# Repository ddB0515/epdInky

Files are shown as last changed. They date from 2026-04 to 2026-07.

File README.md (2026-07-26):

# epdInky

ESP32-P4 board for driving RAW E-Ink display panels, epdInky is powered by ESP32-P4 and companion ESP32-C6 for WiFi

If you wanna get one for yourself hop to shop: https://shop.fasani.de/en_US/products/epdinky

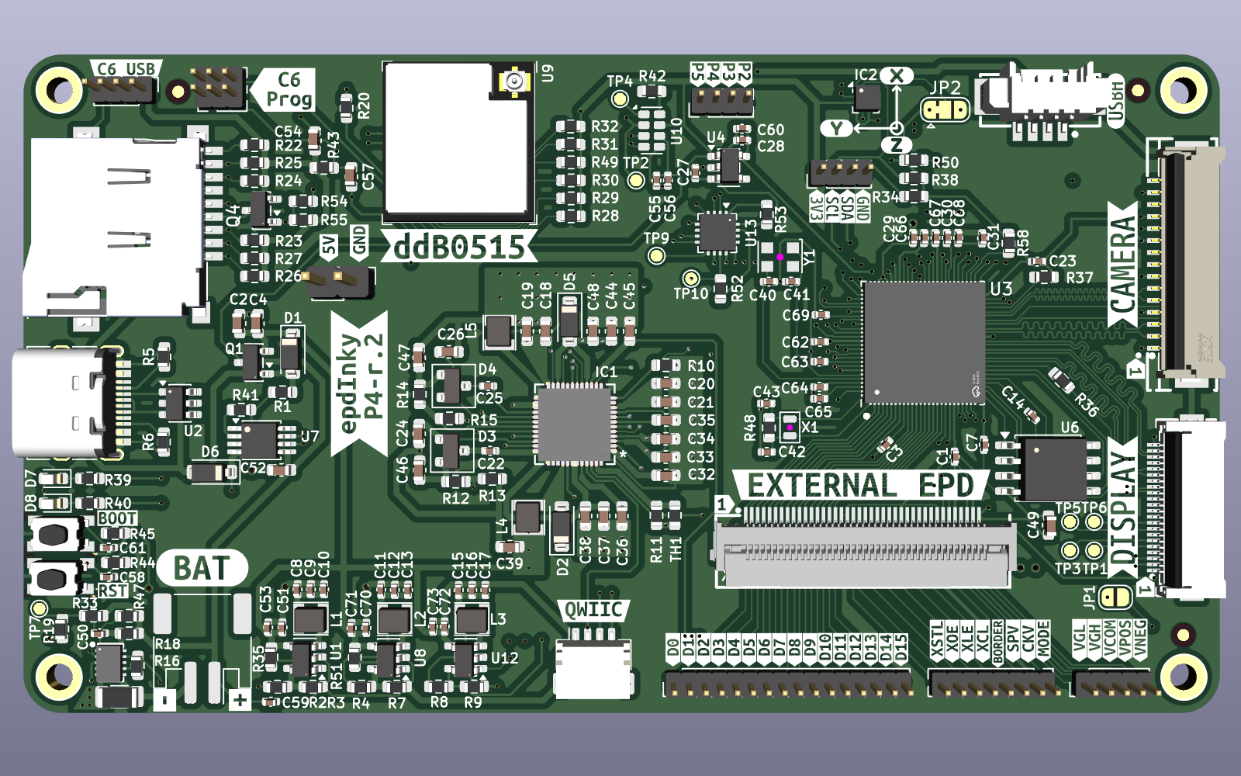
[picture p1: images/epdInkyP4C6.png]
Front Photo


# Hardware Specifications

## SoC
- **Model:** Espressif Systems ESP32-P4NRW32

## CPU
- Dual-core 32-bit RISC-V High-Performance (HP) CPU
  - Up to **400 MHz**
  - AI instruction extension
  - Single-precision FPU
- Single-core RISC-V Low-Power (LP) MCU
  - Up to **40 MHz**

## Memory
- 768 KB HP L2MEM (shared by dual-core CPU)
- 32 KB LP SRAM
- 8 KB TCM (for LP MCU core)
- 32 MB PSRAM

## Storage
- **Internal ROM**
  - 128 KB HP ROM
  - 16 KB LP ROM
- **Flash**
  - 32 MB QSPI NOR Flash
- **Expandable**
  - MicroSD card slot

## Graphics & Video
- **GPU:** 2D Pixel Processing Accelerator (PPA)
- **VPU:** H.264 and JPEG codec support

## Camera
- MIPI CSI camera sensor interface

## Wireless
- **Companion chip:** ESP32-C6
- 2.4 GHz Wi-Fi 6
- Bluetooth 5.x Low Energy (LE)
- IEEE 802.15.4 radio
  - Zigbee
  - Thread
  - Matter

## USB
- USB Type-C port
  - Power
  - Debugging

## Sensors
- 6-axis KXTJ3-1057 motion sensor
  - Portrait/landscape orientation detection

## Miscellaneous
- Reset button
- Boot button
- Power LED
- Battery LED
- RV-3028-C7 RTC with timed interrupt wake-up support

## Power Supply
- 5V via USB Type-C
- JST battery connector

## Dimensions
- **100 × 55 mm**

## I2C peripherals:

- TPS651851RSLR - PMIC for e-Ink (I2C addr: 0x68)
- KXTJ3-1057 - 3-axis accelerometar  (I2C addr: 0x0F)
- RV-3028-C7 - RTC (I2C addr: 0x52)
- STC3115AIQT - Fuel guage (I2C addr: 0x70)
- TCA6408ARGTR - GPIO Extender (I2C addr: 0x21)
- TP4056 Battery charger (500mA)

Software side:

Currently examples use [FastEPD](https://github.com/bitbank2/FastEPD/) library and plan is to support
* epdiy
* TRMNL
* HA (custom FW)

List of panels tested and working (keep in mind 2/4bit support for panels is still WIP and will be some time to do it)

| Panel | Resulution | 8/16bit | Gray levels | Pin count | Tested |
| ----- | --- | --- | --- | --- | --- |
| ED070KH1 | 1680x1264 | 16 bit | 1/2/4 | 40 pin | 1 bit only |
| ED097TC2 | 1200x825 | 8 bit | 1/2/4 | 33 pin | 1 bit only |
| ES133TT3 | 2200x1650 | 16 bit | 1/2/4 | 39 pin | 1 bit only |
| ED115OC1 | 2760x2070 | 16 bit | 1/2/4 | 40 pin | 1 bit only |
| ED113TC1| 2400x1034 | 16 bit | 1/2/4 | 50 pin | 1 bit only |
| ED052TC4 | 1280x720 | 8 bit | 1/2/4 | 50 pin | 1 bit only |
| ED060SCN | 800x600 | 8 bit| 1/2/4 | 34 pin | 1 bit only |
| ED060SCP | 800x600 | 8 bit| 1/2/4 | 34 pin | 1 bit only |
| ED060SC7 | 800x600 | 8 bit| 1/2/4 | 34 pin | 1 bit only |
| ET017QG1 |320x240| 8 bit | 1/2/4 | 39 pin| 1 bit only |
| ED103TC2 | 1872x1404 | 16 bit | 1/2/4 | 40 pin| 1 bit only |
| ED078KC1 | 1872x1404 | 16 bit | 1/2/4 | 40 pin| 1 bit only |
| | | | | | |
| | | | | | |

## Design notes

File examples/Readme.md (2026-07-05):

# Examples

This directory contains example applications demonstrating the capabilities of **epdInky** and the supported hardware peripherals. The examples range from basic e-paper rendering to Wi-Fi, camera, MIPI DSI, and JSON-based applications.

## Directory Structure

```text
examples/
├── epd/
│   ├── basic/             # Basic e-paper drawing example
│   ├── calendar/          # Calendar application
│   ├── FastJsonBasic/     # FastJson basic usage
│   ├── FastJsonBLE/       # FastJson over Bluetooth LE
│   └── matrix_editor/     # Interactive pixel matrix editor
├── csi/                   # MIPI CSI camera examples
├── mipi/
│   └── mipi_dsi_a260/     # MIPI DSI display example
└── wifi/                  # Wi-Fi networking examples
```

## Requirements

Before building any example, make sure you have:

- ESP-IDF installed and configured
- A supported ESP32 target
- The required display and peripherals connected
- All project dependencies installed

## Building an Example

Each example is an independent ESP-IDF project.

```bash
cd examples/epd/basic

idf.py set-target esp32p4
idf.py build
idf.py flash monitor
```

Replace the directory with the example you want to build.

## Examples

### EPD

| Example | Description |
|---|---|
| **basic** | A minimal example demonstrating how to initialize the e-paper display and render basic graphics and text. |
| **calendar** | Displays a calendar interface using the e-paper display, including text rendering and layout management. |
| **matrix_editor** | Interactive pixel editor demonstrating framebuffer manipulation, drawing primitives, and partial display updates. |
| **FastJsonBasic** | Demonstrates using the FastJson library for parsing and generating JSON data. |
| **FastJsonBLE** | Demonstrates Bluetooth LE communication using FastJson for data serialization and exchange. |

### CSI

Camera interface examples demonstrating:

- MIPI CSI initialization
- Frame capture
- Image processing pipelines

### MIPI

#### `mipi_dsi_a260`

Demonstrates driving a MIPI DSI display, including:

- Display initialization
- Framebuffer rendering
- Screen updates

### Wi-Fi

Networking examples showing how to:

- Connect to a Wi-Fi access point
- Perform network communication
- Build connected applications

## Adding New Examples

New examples should follow the standard ESP-IDF project layout:

```text
example_name/
├── main/
├── CMakeLists.txt
├── README.md
└── sdkconfig.defaults
```

Keeping each example self-contained makes it easier to build, understand, and maintain.

## Hardware Requirements

Some examples require additional hardware, such as:

- E-paper display
- MIPI DSI display
- MIPI CSI camera
- Bluetooth LE device
- Wi-Fi network

Refer to each example's source code and configuration for hardware-specific requirements.

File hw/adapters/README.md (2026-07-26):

# List of adapters so far that are manufactured and tested

### AllInOneAdapter


This adapter have:<br>
* 40 pin (this is double side contacts) so some panels will need to reverse it (due to opposite pins but works)<br>
* 34 pin (this is double side contacts) so some panels will need to reverse it (due to opposite pins but works)<br>
* 33 pin (bottom side contacts) as didn't find any reverse panels but if do in future can be updated to support it <br>

### AllInOneAdapter-39pin

This adapter have 3 39pin connectors for different models but different style panels could be connected (check schematic)<br>
* ED133UT2<br>
* ED060SC4<br>
* ET107QG1 (U2 on PCB is not populated (for backlight)<br>

### ED052TC4-Adapter


### ED060SC7-Adapter


### ED113TC1-Adapter


### EPD-Adapter
This is generic universal adapter for prototyping when want to have exposed pads (with header ot not) 



### ES133TT3-Adapter


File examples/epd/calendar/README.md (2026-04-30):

| Supported Targets | ESP32-P4 |
| --- | --- |

# EPD Basic DEMOs

This example shows how to use FASTEPD library with epdInky ESP32-P4C6.r2 board

# Cloning repo

YOu have few ways doing checkout code and compile

```
git clone --recurse-submodules https://github.com/ddB0515/epdInky.git

or if you have cloned it already (you need to update submodule)

git submodule update --init --recursive

```
After this step is done you need manually to create one file in component (this is workaround until FastEPD gets IDF component registy)

Put this content into: components/FastEPD/idf_component.yml
```
version: "2.0.1"
description: "Optimized library for driving parallel eink displays with the ESP32"
url: "https://github.com/bitbank2/FastEPD"
license: "Apache-2.0 license"
```
Without this you will get errors building 
```
CMake Error at /home/user/.espressif/v6.0/esp-idf/tools/cmake/build.cmake:695 (message):
  ERROR: The "path" field in the manifest file
  "/home/user/epdInky/examples/epd/matrix_editor/main/components/FastEPD/idf_component.yml"
  does not point to a directory.  You can safely remove this field from the
  manifest if this project is an example copied from a component repository.
  The dependency will be downloaded from the ESP component registry.
```

## How to use the example

### Hardware Required

* An epdInky ESP32-P4C6.r2 development board, adapter for eInk panel (check main README.md)
* SDCard needs to be present (as is part of demo) but used for test purposes

### Hardware Connection

The connection between epdInky ESP32-P4C6.r2 is provided via 40pin FPC cable to adapter which enable connection to eInk panel

### Configure

To change panel details refer to `main.c` and change details for your panel

```
If you are using 8bit panel you have to change board config (BB_PANEL_EPDINKY_P4 or BB_PANEL_EPDINKY_P4_16)

8Bit
    int rc = bbepInitPanel(&bbep, BB_PANEL_EPDINKY_P4, 20000000);

16Bit
    int rc = bbepInitPanel(&bbep, BB_PANEL_EPDINKY_P4_16, 20000000);

```
Next section is PANEL itself (size W/H and flags) this example I'm using ED113TC1 panel
```
bbepSetPanelSize(&bbep, 2400, 1034, BB_PANEL_FLAG_MIRROR_Y, -1000); // ED113TC1
```

after all is done you can BUILD

Run `idf.py menuconfig` and go to `Example Configuration`:
2 Options needs to be enabled
- PSRAM
- Chip ID to be < 3.0 (old version)
(this should be already enabled in default sdkconfig)

### Build and Flash

Run `idf.py -p PORT build flash monitor` to build, flash and monitor the project. A LVGL widget should show up on the LCD as expected.

The first time you run `idf.py` for the example will cost extra time as the build system needs to address the component dependencies and downloads the missing components from the ESP Component Registry into `managed_components` folder.

(To exit the serial monitor, type ``Ctrl-]``.)

See the [Getting Started Guide](https://docs.espressif.com/projects/esp-idf/en/latest/get-started/index.html) for full steps to configure and use ESP-IDF to build projects.

# USAGE

In my case when connected to WiFI find your IP address and connect to it (in my case was: 192.168.1.82)
So you need to open
```
http://192.168.1.82/matrix
```
And you should be on Matrix Editor and ready to modify your example as you wish, once you have your matrix for the panel you could open PR for FastEPD or here

### Example Output

```bash
...
Build:Jul 10 2024
rst:0x17 (CHIP_USB_UART_RESET),boot:0xc (SPI_FAST_FLASH_BOOT)
Core0 Saved PC:0x40009034
--- 0x40009034: s_test_psram at /home/dale/.espressif/v6.0/esp-idf/components/esp_psram/system_layer/esp_psram.c:617
Core1 Saved PC:0x4fc012c6
--- 0x4fc012c6: ets_ds_enable in ROM
SPI mode:DIO, clock div:1
load:0x4ff33ce0,len:0x15e0
load:0x4ff29ed0,len:0xe18
load:0x4ff2cbd0,len:0x359c
entry 0x4ff29eda
I (27) boot: ESP-IDF v6.0 2nd stage bootloader
I (28) boot: compile time Apr 30 2026 13:01:58
I (28) boot: Multicore bootloader
I (30) boot: chip revision: v1.0
I (30) boot: efuse block revision: v0.3
I (34) boot.esp32p4: SPI Speed      : 80MHz
I (38) boot.esp32p4: SPI Mode       : DIO
I (42) boot.esp32p4: SPI Flash Size : 2MB
I (45) boot: Enabling RNG early entropy source...
I (50) boot: Partition Table:
I (53) boot: ## Label            Usage          Type ST Offset   Length
I (59) boot:  0 nvs              WiFi data        01 02 00009000 00006000
I (65) boot:  1 phy_init         RF data          01 01 0000f000 00001000
I (72) boot:  2 factory          factory app      00 00 00010000 00100000
I (79) boot: End of partition table
I (82) esp_image: segment 0: paddr=00010020 vaddr=40030020 size=17998h ( 96664) map
I (104) esp_image: segment 1: paddr=000279c0 vaddr=30100000 size=00068h (   104) load
I (106) esp_image: segment 2: paddr=00027a30 vaddr=4ff00000 size=085e8h ( 34280) load
I (114) esp_image: segment 3: paddr=00030020 vaddr=40000020 size=24e7ch (151164) map
I (138) esp_image: segment 4: paddr=00054ea4 vaddr=4ff085e8 size=076c0h ( 30400) load
I (145) esp_image: segment 5: paddr=0005c56c vaddr=4ff0fd00 size=03258h ( 12888) load
I (152) boot: Loaded app from partition at offset 0x10000
I (153) boot: Disabling RNG early entropy source...
I (165) hex_psram: vendor id    : 0x0d (AP)
I (165) hex_psram: Latency      : 0x01 (Fixed)
I (166) hex_psram: DriveStr.    : 0x00 (25 Ohm)
I (166) hex_psram: dev id       : 0x03 (generation 4)
I (171) hex_psram: density      : 0x07 (256 Mbit)
I (175) hex_psram: good-die     : 0x06 (Pass)
I (179) hex_psram: SRF          : 0x02 (Slow Refresh)
I (184) hex_psram: BurstType    : 0x00 ( Wrap)
I (188) hex_psram: BurstLen     : 0x03 (2048 Byte)
I (193) hex_psram: BitMode      : 0x01 (X16 Mode)
I (197) hex_psram: Readlatency  : 0x04 (14 cycles@Fixed)
I (202) hex_psram: DriveStrength: 0x00 (1/1)
I (206) MSPI Timing: Enter psram timing tuning
I (383) esp_psram: Found 32MB PSRAM device
I (384) esp_psram: Speed: 200MHz
I (387) hex_psram: psram CS IO is dedicated
I (387) cpu_start: Multicore app
I (1372) esp_psram: SPI SRAM memory test OK
I (1383) cpu_start: GPIO 38 and 37 are used as console UART I/O pins
I (1383) cpu_start: Pro cpu start user code
I (1383) cpu_start: cpu freq: 360000000 Hz
I (1385) app_init: Application information:
I (1389) app_init: Project name:     basic
I (1393) app_init: App version:      1eac6ff-dirty
I (1397) app_init: Compile time:     Apr 30 2026 13:01:56
I (1402) app_init: ELF file SHA256:  042d7002f...
I (1407) app_init: ESP-IDF:          v6.0
I (1411) efuse_init: Min chip rev:     v1.0
I (1415) efuse_init: Max chip rev:     v1.99 
I (1419) efuse_init: Chip rev:         v1.0
I (1423) heap_init: Initializing. RAM available for dynamic allocation:
I (1429) heap_init: At 4FF15970 len 00025650 (149 KiB): RETENT_RAM
I (1435) heap_init: At 4FF3AFC0 len 00004BF0 (18 KiB): RAM
I (1440) heap_init: At 4FF40000 len 00060000 (384 KiB): RAM
I (1446) heap_init: At 50108080 len 00007F80 (31 KiB): RTCRAM
I (1451) heap_init: At 30100068 len 00001F98 (7 KiB): TCM
I (1456) esp_psram: Adding pool of 32768K of PSRAM memory to heap allocator
I (1463) spi_flash: detected chip: generic
I (1466) spi_flash: flash io: dio
W (1469) spi_flash: Detected size(16384k) larger than the size in the binary image header(2048k). Using the size in the binary image header.
I (1482) sleep_gpio: Configure to isolate all GPIO pins in sleep state
I (1488) sleep_gpio: Enable automatic switching of GPIO sleep configuration
I (1495) main_task: Started on CPU0
I (1505) esp_psram: Reserving pool of 32K of internal memory for DMA/internal allocations
I (1505) main_task: Calling app_main()
I (1505) eInky-P4: i2c_master_init ESP_OK
I (1515) eInky-P4: tca6408_init...
     0  1  2  3  4  5  6  7  8  9  a  b  c  d  e  f
00: -- -- -- -- -- -- -- -- -- -- -- -- -- -- -- 0f 
10: -- -- -- -- -- -- -- -- -- -- -- -- -- -- -- -- 
20: -- 21 -- -- -- -- -- -- -- -- -- -- -- -- -- -- 
30: -- -- -- -- -- -- -- -- -- -- -- -- -- -- -- -- 
40: -- -- -- -- -- -- -- -- -- -- -- -- -- -- -- -- 
50: -- -- 52 -- -- -- -- -- -- -- -- -- -- -- -- -- 
60: -- -- -- -- -- -- -- -- 68 -- -- -- -- -- -- -- 
70: 70 -- -- -- -- -- -- -- -- -- -- -- -- -- -- -- 
W (1595) i2c.master: Timeout value exceeds the maximum supported value, rounded down to maximum supported value: 53687091 us
...
W (46865) i2c.master: Timeout value exceeds the maximum supported value, rounded down to maximum supported value: 53687091 us
I (48315) main_task: Returned from app_main()
...
```

## Troubleshooting

For any technical queries, please open an [issue](https://github.com/ddB0515/epdInky/issues) on GitHub. We will get back to you soon.

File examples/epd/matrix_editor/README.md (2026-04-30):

| Supported Targets | ESP32-P4 |
| --- | --- |

# EPD Matrix Editor

This example shows how to use Web GUI for custom Matrix editor needed to make for new panels to get 16 levels (4bit) gray colours.
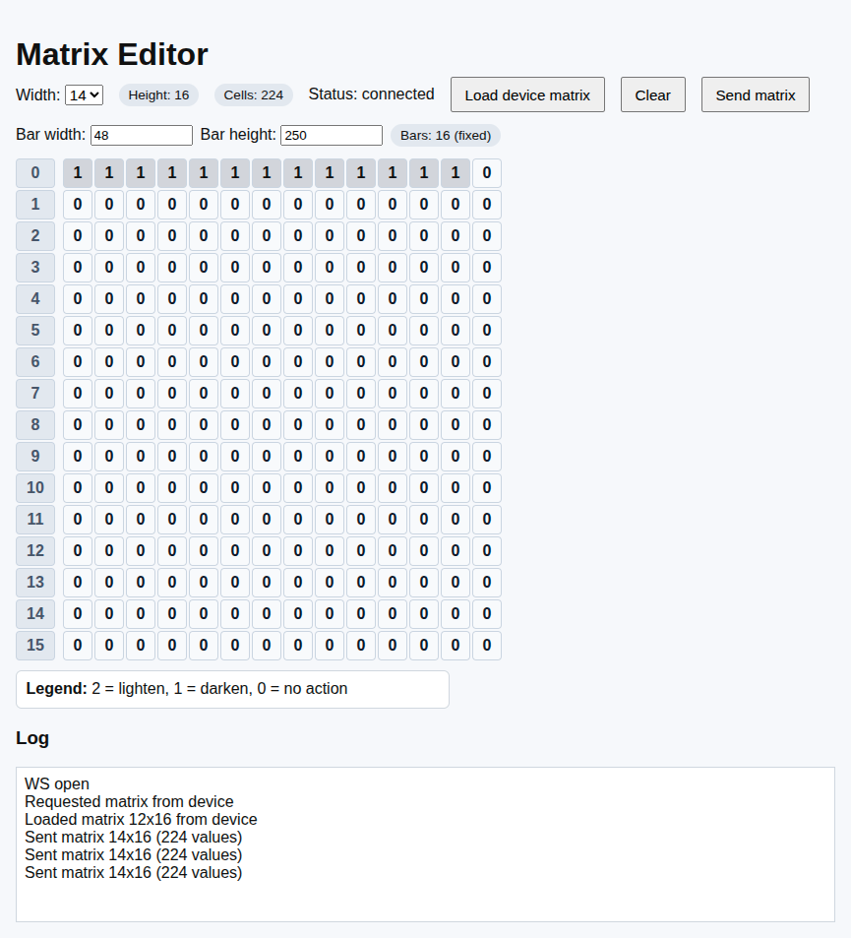
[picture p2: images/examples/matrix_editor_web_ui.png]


When run matrix editor on a device you going to be able to change settings in realtime (check image top) and adjust it on the fly

DEFAULT

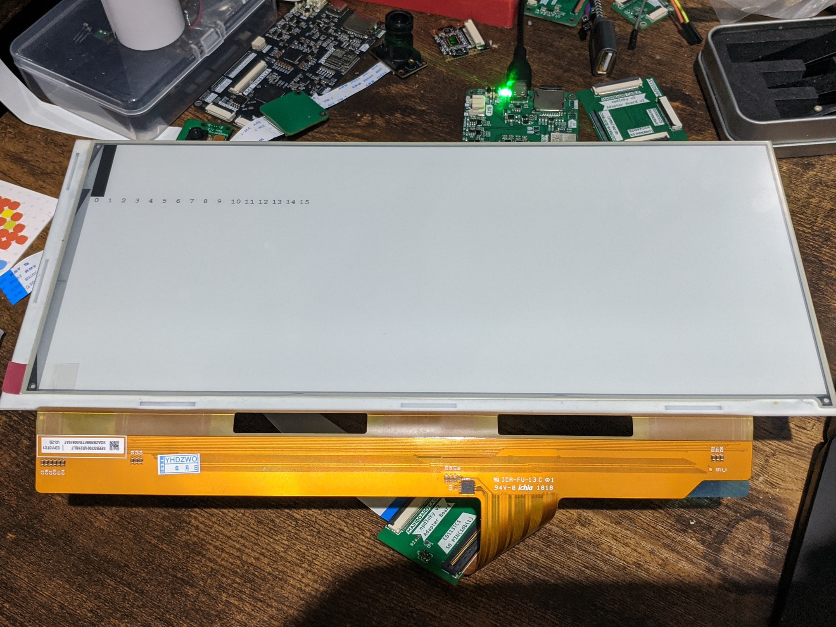
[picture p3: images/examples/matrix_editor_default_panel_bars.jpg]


MODIFIED

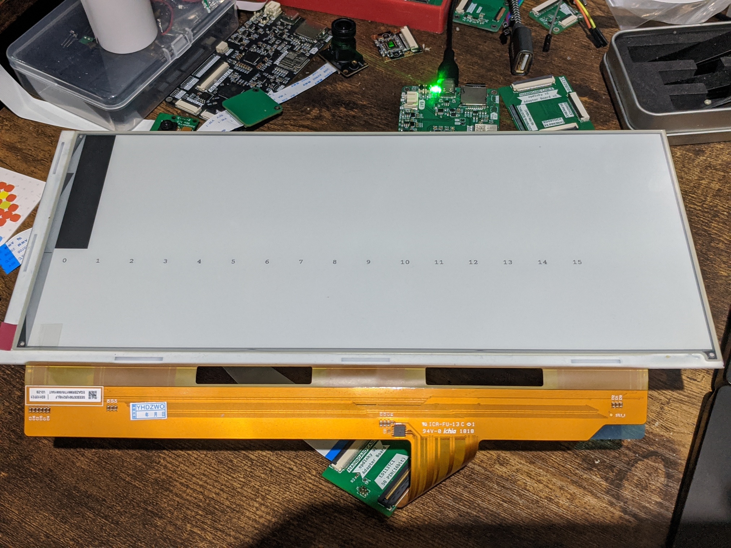
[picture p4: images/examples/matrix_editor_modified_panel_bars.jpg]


# Cloning repo

YOu have few ways doing checkout code and compile

```
git clone --recurse-submodules https://github.com/ddB0515/epdInky.git

or if you have cloned it already (you need to update submodule)

git submodule update --init --recursive

```
After this step is done you need manually to create one file in component (this is workaround until FastEPD gets IDF component registy)

Put this content into: components/FastEPD/idf_component.yml
```
version: "2.0.1"
description: "Optimized library for driving parallel eink displays with the ESP32"
url: "https://github.com/bitbank2/FastEPD"
license: "Apache-2.0 license"
```
Without this you will get errors building 
```
CMake Error at /home/user/.espressif/v6.0/esp-idf/tools/cmake/build.cmake:695 (message):
  ERROR: The "path" field in the manifest file
  "/home/user/epdInky/examples/epd/matrix_editor/main/components/FastEPD/idf_component.yml"
  does not point to a directory.  You can safely remove this field from the
  manifest if this project is an example copied from a component repository.
  The dependency will be downloaded from the ESP component registry.
```

## How to use the example

### Hardware Required

* An epdInky ESP32-P4C6.r2 development board, adapter for eInk panel (check main README.md)
* SDCard needs to be present (as is part of demo) but used for test purposes
### Hardware Connection

The connection between epdInky ESP32-P4C6.r2 is provided via 40pin FPC cable to adapter which enable connection to eInk panel

### Configure

In `main.h` before you build change default WIFI settings to your network so you can connect to WiFi and use editor

```
#define EXAMPLE_ESP_WIFI_SSID      "WIFI_SSID"
#define EXAMPLE_ESP_WIFI_PASS      "WIFI_PASSWORD"
```
To change panel details refer to `epd_functions.c` and change details for your panel

```
If you are using 8bit panel you have to change board config (BB_PANEL_EPDINKY_P4 or BB_PANEL_EPDINKY_P4_16)

8Bit
    int rc = bbepInitPanel(&bbep, BB_PANEL_EPDINKY_P4, 20000000); //BB_PANEL_EPDINKY_P4_16

16Bit
    int rc = bbepInitPanel(&bbep, BB_PANEL_EPDINKY_P4_16, 20000000); //BB_PANEL_EPDINKY_P4_16

```
Next section is PANEL itself (size W/H and flags) this example I'm using ED113TC1 panel
```
bbepSetPanelSize(&bbep, 2400, 1034, BB_PANEL_FLAG_MIRROR_Y, 0); // ED113TC1
```

after all is done you can BUILD

Run `idf.py menuconfig` and go to `Example Configuration`:
2 Options needs to be enabled
- PSRAM
- Chip ID to be < 3.0 (old version)
(this should be already enabled in default sdkconfig)

### Build and Flash

Run `idf.py -p PORT build flash monitor` to build, flash and monitor the project. A LVGL widget should show up on the LCD as expected.

The first time you run `idf.py` for the example will cost extra time as the build system needs to address the component dependencies and downloads the missing components from the ESP Component Registry into `managed_components` folder.

(To exit the serial monitor, type ``Ctrl-]``.)

See the [Getting Started Guide](https://docs.espressif.com/projects/esp-idf/en/latest/get-started/index.html) for full steps to configure and use ESP-IDF to build projects.

# USAGE

In my case when connected to WiFI find your IP address and connect to it (in my case was: 192.168.1.82)
So you need to open
```
http://192.168.1.82/matrix
```
And you should be on Matrix Editor and ready to modify your example as you wish, once you have your matrix for the panel you could open PR for FastEPD or here

### Example Output

```bash
...
Build:Jul 10 2024
rst:0x17 (CHIP_USB_UART_RESET),boot:0x31c (SPI_FAST_FLASH_BOOT)
Core0 Saved PC:0x40009024
--- 0x40009024: s_test_psram at /home/user/.espressif/v6.0/esp-idf/components/esp_psram/system_layer/esp_psram.c:617
Core1 Saved PC:0x4fc012ca
--- 0x4fc012ca: ets_ds_enable in ROM
SPI mode:DIO, clock div:1
load:0x4ff33ce0,len:0x15e0
load:0x4ff29ed0,len:0xe18
load:0x4ff2cbd0,len:0x359c
entry 0x4ff29eda
I (28) boot: ESP-IDF v6.0 2nd stage bootloader
I (28) boot: compile time Apr 29 2026 22:49:13
I (28) boot: Multicore bootloader
I (30) boot: chip revision: v1.0
I (31) boot: efuse block revision: v0.3
I (34) boot.esp32p4: SPI Speed      : 80MHz
I (38) boot.esp32p4: SPI Mode       : DIO
I (42) boot.esp32p4: SPI Flash Size : 2MB
I (46) boot: Enabling RNG early entropy source...
I (50) boot: Partition Table:
I (53) boot: ## Label            Usage          Type ST Offset   Length
I (59) boot:  0 nvs              WiFi data        01 02 00009000 00006000
I (66) boot:  1 phy_init         RF data          01 01 0000f000 00001000
I (72) boot:  2 factory          factory app      00 00 00010000 00100000
I (79) boot: End of partition table
I (82) esp_image: segment 0: paddr=00010020 vaddr=40080020 size=3df24h (253732) map
I (127) esp_image: segment 1: paddr=0004df4c vaddr=30100000 size=00068h (   104) load
I (129) esp_image: segment 2: paddr=0004dfbc vaddr=4ff00000 size=0205ch (  8284) load
I (133) esp_image: segment 3: paddr=00050020 vaddr=40000020 size=7aa58h (502360) map
I (212) esp_image: segment 4: paddr=000caa80 vaddr=4ff0205c size=0e7cch ( 59340) load
I (223) esp_image: segment 5: paddr=000d9254 vaddr=4ff10880 size=035f8h ( 13816) load
I (231) boot: Loaded app from partition at offset 0x10000
I (231) boot: Disabling RNG early entropy source...
I (243) hex_psram: vendor id    : 0x0d (AP)
I (243) hex_psram: Latency      : 0x01 (Fixed)
I (243) hex_psram: DriveStr.    : 0x00 (25 Ohm)
I (244) hex_psram: dev id       : 0x03 (generation 4)
I (248) hex_psram: density      : 0x07 (256 Mbit)
I (253) hex_psram: good-die     : 0x06 (Pass)
I (257) hex_psram: SRF          : 0x02 (Slow Refresh)
I (262) hex_psram: BurstType    : 0x00 ( Wrap)
I (266) hex_psram: BurstLen     : 0x03 (2048 Byte)
I (270) hex_psram: BitMode      : 0x01 (X16 Mode)
I (275) hex_psram: Readlatency  : 0x04 (14 cycles@Fixed)
I (280) hex_psram: DriveStrength: 0x00 (1/1)
I (284) MSPI Timing: Enter psram timing tuning
I (461) esp_psram: Found 32MB PSRAM device
I (462) esp_psram: Speed: 200MHz
I (465) hex_psram: psram CS IO is dedicated
I (465) cpu_start: Multicore app
I (1450) esp_psram: SPI SRAM memory test OK
I (1461) cpu_start: GPIO 38 and 37 are used as console UART I/O pins
I (1461) cpu_start: Pro cpu start user code
I (1461) cpu_start: cpu freq: 360000000 Hz
I (1463) app_init: Application information:
I (1467) app_init: Project name:     matrix_editor
I (1472) app_init: App version:      e2e2744
I (1476) app_init: Compile time:     Apr 29 2026 22:49:11
I (1481) app_init: ELF file SHA256:  e76bba324...
I (1485) app_init: ESP-IDF:          v6.0
I (1489) efuse_init: Min chip rev:     v1.0
I (1493) efuse_init: Max chip rev:     v1.99 
I (1497) efuse_init: Chip rev:         v1.0
I (1501) heap_init: Initializing. RAM available for dynamic allocation:
I (1507) heap_init: At 4FF17810 len 000237B0 (141 KiB): RETENT_RAM
I (1513) heap_init: At 4FF3AFC0 len 00004BF0 (18 KiB): RAM
I (1518) heap_init: At 4FF40000 len 00060000 (384 KiB): RAM
I (1524) heap_init: At 50108080 len 00007F80 (31 KiB): RTCRAM
I (1529) heap_init: At 30100068 len 00001F98 (7 KiB): TCM
I (1534) esp_psram: Adding pool of 32768K of PSRAM memory to heap allocator
I (1542) spi_flash: detected chip: generic
I (1545) spi_flash: flash io: dio
W (1548) spi_flash: Detected size(16384k) larger than the size in the binary image header(2048k). Using the size in the binary image header.
I (1579) sleep_gpio: Configure to isolate all GPIO pins in sleep state
I (1584) sleep_gpio: Enable automatic switching of GPIO sleep configuration
I (1591) H_SDIO_DRV: sdio_data_to_rx_buf_task started
I (1591) main_task: Started on CPU0
I (1601) esp_psram: Reserving pool of 32K of internal memory for DMA/internal allocations
I (1611) main_task: Calling app_main()
I (1611) eInky-P4: i2c_master_init ESP_OK
I (1611) eInky-P4: tca6408_init...
     0  1  2  3  4  5  6  7  8  9  a  b  c  d  e  f
00: -- -- -- -- -- -- -- -- -- -- -- -- -- -- -- 0f 
10: -- -- -- -- -- -- -- -- -- -- -- -- -- -- -- -- 
20: -- 21 -- -- -- -- -- -- -- -- -- -- -- -- -- -- 
30: -- -- -- -- -- -- -- -- -- -- -- -- -- -- -- -- 
40: -- -- -- -- -- -- -- -- -- -- -- -- -- -- -- -- 
50: -- -- 52 -- -- -- -- -- -- -- -- -- -- -- -- -- 
60: -- -- -- -- -- -- -- -- 68 -- -- -- -- -- -- -- 
70: 70 -- -- -- -- -- -- -- -- -- -- -- -- -- -- -- 
I (1661) epd_functions: FastEPD init
I (1661) epd_functions: bbepInitPanel returned 0
W (1671) epd_functions: EPD not initialized; call epd_init() first
W (1671) epd_functions: bbepSetCustomMatrix OK
W (1741) i2c.master: Timeout value exceeds the maximum supported value, rounded down to maximum supported value: 53687091 us
W (1741) i2c.master: Timeout value exceeds the maximum supported value, rounded down to maximum supported value: 53687091 us
W (3731) epd_functions: bbepFullUpdate OK
I (3731) sd_card_fns: Initializing SD card
I (3731) sd_card_fns: Using SDMMC peripheral
I (3731) sd_card_fns: Mounting filesystem
I (3771) sd_card_fns: Filesystem mounted
Name: SD32G
Type: SDHC
Speed: 20.00 MHz (limit: 20.00 MHz)
Size: 29819MB
CSD: ver=2, sector_size=512, capacity=61069312 read_bl_len=9
SSR: bus_width=4
I (3781) sd_card_fns: Opening file /sdcard/hello.txt
I (3821) sd_card_fns: File written
I (3821) transport: Attempt connection with slave: retry[0]
W (3821) H_SDIO_DRV: Reset slave using GPIO[54]
I (3821) os_wrapper_esp: GPIO [54] configured
I (5351) sdio_wrapper: SDIO master: Slot 1, Data-Lines: 4-bit Freq(KHz)[40000 KHz]
I (5351) sdio_wrapper: GPIOs: CLK[18] CMD[19] D0[23] D1[22] D2[21] D3[20] Slave_Reset[54]
I (5351) sdio_wrapper: Queues: Tx[20] Rx[20] SDIO-Rx-Mode[1]
I (5391) sdio_wrapper: Function 0 Blocksize: 512
I (5391) sdio_wrapper: Function 1 Blocksize: 512
I (5491) H_SDIO_DRV: Card init success, TRANSPORT_RX_ACTIVE
I (5491) transport: set_transport_state: 1
I (5491) transport: Waiting for esp_hosted slave to be ready
I (5591) H_SDIO_DRV: SDIO Host operating in STREAMING MODE
I (5591) H_SDIO_DRV: Open data path at slave
I (5591) H_SDIO_DRV: Starting SDIO process rx task
I (5611) H_SDIO_DRV: Received ESP_PRIV_IF type message
I (5611) transport: Received INIT event from ESP32 peripheral
I (5611) transport: EVENT: 12
I (5621) transport: Identified slave [esp32c6]
I (5621) transport: SDIO mode: slave: streaming, host: streaming
I (5631) transport: EVENT: 11
I (5631) transport: capabilities: 0xd
I (5631) transport: Features supported are:
I (5641) transport:      * WLAN
I (5641) transport:        - HCI over SDIO
I (5641) transport:        - BLE only
I (5641) transport: EVENT: 13
I (5651) transport: ESP board type is : 13 

I (5651) transport: Base transport is set-up, TRANSPORT_TX_ACTIVE
I (5661) H_API: Transport active
I (5661) transport: Slave chip Id[12]
I (5661) transport: raw_tp_dir[-], flow_ctrl: low[60] high[80]
I (5671) transport: transport_delayed_init
I (5671) esp_cli: Registering command: crash
I (5681) esp_cli: Registering command: reboot
I (5681) esp_cli: Registering command: mem-dump
I (5691) esp_cli: Registering command: task-dump
I (5691) esp_cli: Registering command: cpu-dump
I (5691) esp_cli: Registering command: heap-trace
I (5701) esp_cli: Registering command: sock-dump
I (5701) esp_cli: Registering command: host-power-save
I (5711) hci_stub_drv: Host BT Support: Disabled
I (5711) H_SDIO_DRV: Received INIT event
I (5721) H_SDIO_DRV: Event type: 0x22
I (5721) H_SDIO_DRV: Write thread started
I (6591) RPC_WRAP: Coprocessor Boot-up
W (6751) sd_card_wifi: esp_wifi_init
W (6761) sd_card_wifi: Co-processor Name   : network_adapter
W (6761) sd_card_wifi: Co-processor Version: 2.12.3
W (6761) sd_card_wifi: Co-processor IDF Ver: v6.0
W (6761) sd_card_wifi: Co-processor Time   : 
W (6771) sd_card_wifi: Co-processor Date   : 
I (6891) eInky-P4: Doing Wi-Fi Scan
I (6891) rpc_req: Scan start Req

I (6891) RPC_WRAP: ESP Event: wifi station started
I (9431) RPC_WRAP: ESP Event: wifi station started
I (9431) RPC_WRAP: ESP Event: StaScanDone
I (9461) sd_card_wifi: Total APs scanned = 9, actual AP number ap_info holds = 9
I (9461) sd_card_wifi: AP 1 | SSID: TellMyWiFiILoveHer | RSSI: -35 dBm
I (9461) sd_card_wifi: AP 2 | SSID: SKYJKIJV | RSSI: -59 dBm
I (9471) sd_card_wifi: AP 3 | SSID: SKYJKIJV | RSSI: -65 dBm
I (9471) sd_card_wifi: AP 4 | SSID: Hyperoptic Fibre 2533 | RSSI: -78 dBm
I (9481) sd_card_wifi: AP 5 | SSID: TV network | RSSI: -79 dBm
I (9491) sd_card_wifi: AP 6 | SSID: BT-KZF8GS | RSSI: -80 dBm
I (9491) sd_card_wifi: AP 7 | SSID: EE WiFi | RSSI: -80 dBm
I (9501) sd_card_wifi: AP 8 | SSID: Cooleer_945516 | RSSI: -83 dBm
I (9501) sd_card_wifi: AP 9 | SSID: 8347 Hyperoptic Fibre Broadband | RSSI: -88 dBm
I (9511) eInky-P4: Connecting to WiFi
I (9511) sd_card_wifi: Connecting to TellMyWiFiILoveHer...
I (9541) H_API: esp_wifi_remote_connect
I (9561) sd_card_wifi: wifi_init_sta finished.
I (12311) RPC_WRAP: ESP Event: Station mode: Connected
I (12311) esp_wifi_remote: esp_wifi_internal_reg_rxcb: sta: 0x400622d2
--- 0x400622d2: wifi_sta_receive at /home/user/.espressif/v6.0/esp-idf/components/esp_wifi/src/wifi_netif.c:38
I (13341) esp_netif_handlers: sta ip: 192.168.1.82, mask: 255.255.255.0, gw: 192.168.1.1
I (13341) sd_card_wifi: got ip:192.168.1.82
I (13341) sd_card_wifi: connected to ap SSID:TellMyWiFiILoveHer
I (13341) web_server: HTTP/WebSocket server started on port 80
I (13351) main_task: Returned from app_main()
...
```

## Troubleshooting

For any technical queries, please open an [issue](https://github.com/ddB0515/epdInky/issues) on GitHub. We will get back to you soon.

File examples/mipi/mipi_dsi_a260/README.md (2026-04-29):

| Supported Targets | ESP32-P4 |
| --- | --- |

# MIPI DSI LCD Panel Example( Samsung A260 display)

This example shows the general process of installing a MIPI DSI LCD driver, and displays a LVGL widget on the screen.

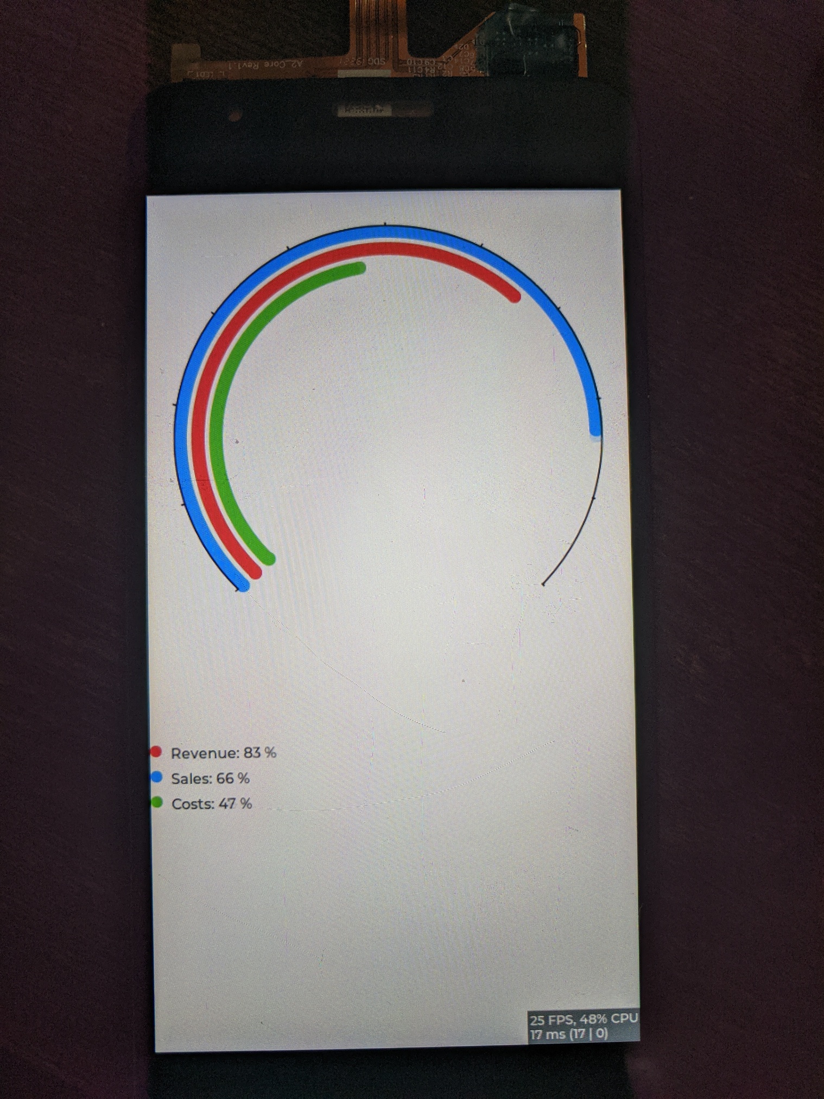
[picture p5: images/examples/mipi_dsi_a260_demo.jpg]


### Hardware Required

* An epdInky ESP32-P4C6.r2 development board, which with MIPI DSI peripheral supported
* Samsung A260 MIPI DSI LCD panel, with 2 data lanes and 1 clock lane, this example support
* Adapter board for 22 pin DSI from board to A260 display
* An USB cable for power supply and programming

### Hardware Connection
Check image

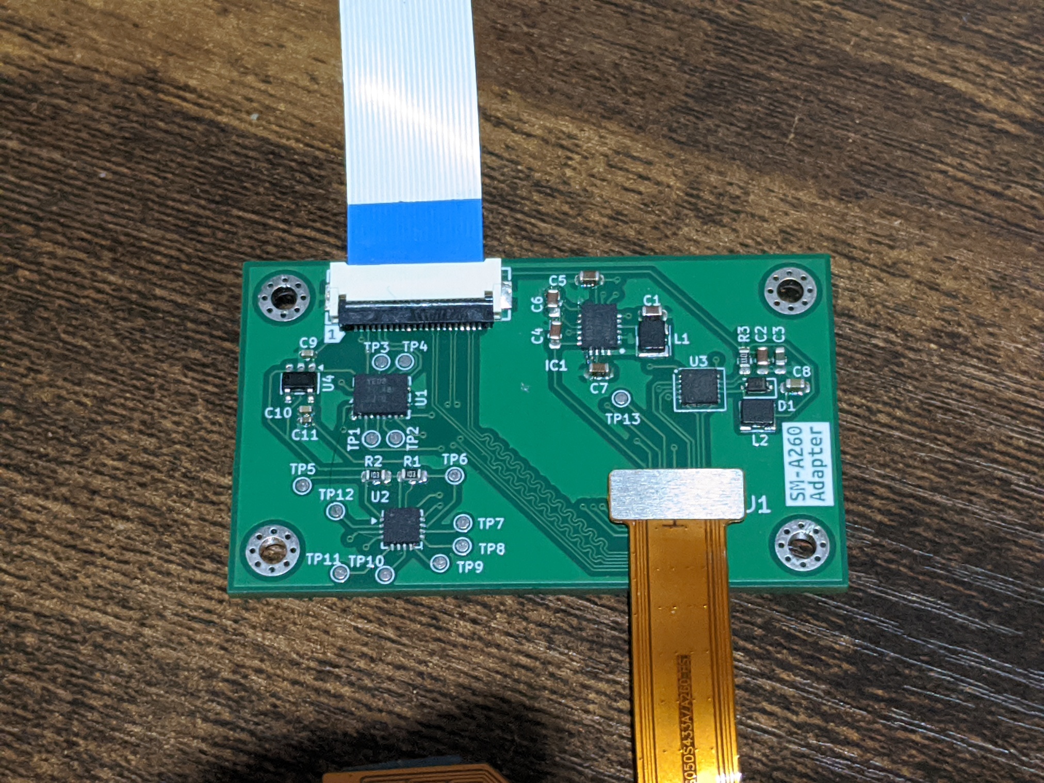
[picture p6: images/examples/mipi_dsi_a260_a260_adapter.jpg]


### Configure

Run `idf.py menuconfig` and go to `Example Configuration`:
2 Options needs to be enabled
- PSRAM
- Chip ID to be < 3.0 (old version)
(this should be already enabled in default sdkconfig)

### Build and Flash

This was tested on ODF v6.0 and don't know if other version works (NOT TESTED)
Run `idf.py -p PORT build flash monitor` to build, flash and monitor the project. A LVGL widget should show up on the LCD as expected.

The first time you run `idf.py` for the example will cost extra time as the build system needs to address the component dependencies and downloads the missing components from the ESP Component Registry into `managed_components` folder.

(To exit the serial monitor, type ``Ctrl-]``.)

See the [Getting Started Guide](https://docs.espressif.com/projects/esp-idf/en/latest/get-started/index.html) for full steps to configure and use ESP-IDF to build projects.

### Example Output
After running on a device you should get something like this
```bash
...
Build:Jul 10 2024
rst:0x17 (CHIP_USB_UART_RESET),boot:0xc (SPI_FAST_FLASH_BOOT)
Core0 Saved PC:0x40009012
--- 0x40009012: s_test_psram at /home/dale/.espressif/v6.0/esp-idf/components/esp_psram/system_layer/esp_psram.c:617
Core1 Saved PC:0x4fc012cc
--- 0x4fc012cc: ets_ds_enable in ROM
SPI mode:DIO, clock div:2
load:0x4ff33ce0,len:0x15e0
load:0x4ff29ed0,len:0xe18
load:0x4ff2cbd0,len:0x359c
entry 0x4ff29eda
I (27) boot: ESP-IDF v6.0 2nd stage bootloader
I (28) boot: compile time Apr 29 2026 21:20:21
I (28) boot: Multicore bootloader
I (30) boot: chip revision: v1.0
I (30) boot: efuse block revision: v0.3
I (34) boot.esp32p4: SPI Speed      : 40MHz
I (38) boot.esp32p4: SPI Mode       : DIO
I (42) boot.esp32p4: SPI Flash Size : 2MB
I (45) boot: Enabling RNG early entropy source...
I (50) boot: Partition Table:
I (53) boot: ## Label            Usage          Type ST Offset   Length
I (59) boot:  0 nvs              WiFi data        01 02 00009000 00006000
I (65) boot:  1 phy_init         RF data          01 01 0000f000 00001000
I (72) boot:  2 factory          factory app      00 00 00010000 00100000
I (79) boot: End of partition table
I (82) esp_image: segment 0: paddr=00010020 vaddr=40060020 size=1550ch ( 87308) map
I (107) esp_image: segment 1: paddr=00025534 vaddr=30100000 size=00068h (   104) load
I (109) esp_image: segment 2: paddr=000255a4 vaddr=4ff00000 size=0aa74h ( 43636) load
I (122) esp_image: segment 3: paddr=00030020 vaddr=40000020 size=56bach (355244) map
I (194) esp_image: segment 4: paddr=00086bd4 vaddr=4ff0aa74 size=04f4ch ( 20300) load
I (200) esp_image: segment 5: paddr=0008bb28 vaddr=4ff0fa00 size=033a0h ( 13216) load
I (208) boot: Loaded app from partition at offset 0x10000
I (208) boot: Disabling RNG early entropy source...
I (221) hex_psram: vendor id    : 0x0d (AP)
I (222) hex_psram: Latency      : 0x01 (Fixed)
I (222) hex_psram: DriveStr.    : 0x00 (25 Ohm)
I (223) hex_psram: dev id       : 0x03 (generation 4)
I (227) hex_psram: density      : 0x07 (256 Mbit)
I (231) hex_psram: good-die     : 0x06 (Pass)
I (236) hex_psram: SRF          : 0x02 (Slow Refresh)
I (240) hex_psram: BurstType    : 0x00 ( Wrap)
I (245) hex_psram: BurstLen     : 0x03 (2048 Byte)
I (249) hex_psram: BitMode      : 0x01 (X16 Mode)
I (253) hex_psram: Readlatency  : 0x04 (14 cycles@Fixed)
I (258) hex_psram: DriveStrength: 0x00 (1/1)
I (262) MSPI Timing: Enter psram timing tuning
I (439) esp_psram: Found 32MB PSRAM device
I (439) esp_psram: Speed: 200MHz
I (443) hex_psram: psram CS IO is dedicated
I (443) cpu_start: Multicore app
I (1428) esp_psram: SPI SRAM memory test OK
I (1439) cpu_start: GPIO 38 and 37 are used as console UART I/O pins
I (1439) cpu_start: Pro cpu start user code
I (1439) cpu_start: cpu freq: 360000000 Hz
I (1441) app_init: Application information:
I (1445) app_init: Project name:     mipi_dsi_a260
I (1450) app_init: App version:      3b1ea4a
I (1454) app_init: Compile time:     Apr 29 2026 21:20:17
I (1459) app_init: ELF file SHA256:  ec6ee88e5...
I (1463) app_init: ESP-IDF:          v6.0
I (1467) efuse_init: Min chip rev:     v0.0
I (1471) efuse_init: Max chip rev:     v1.99 
I (1475) efuse_init: Chip rev:         v1.0
I (1479) heap_init: Initializing. RAM available for dynamic allocation:
I (1485) heap_init: At 4FF248D0 len 000166F0 (89 KiB): RETENT_RAM
I (1491) heap_init: At 4FF3AFC0 len 00004BF0 (18 KiB): RAM
I (1496) heap_init: At 4FF40000 len 00060000 (384 KiB): RAM
I (1502) heap_init: At 50108080 len 00007F80 (31 KiB): RTCRAM
I (1507) heap_init: At 30100068 len 00001F98 (7 KiB): TCM
I (1512) esp_psram: Adding pool of 32768K of PSRAM memory to heap allocator
I (1520) spi_flash: detected chip: generic
I (1522) spi_flash: flash io: dio
W (1526) spi_flash: Detected size(16384k) larger than the size in the binary image header(2048k). Using the size in the binary image header.
I (1539) sleep_gpio: Configure to isolate all GPIO pins in sleep state
I (1544) sleep_gpio: Enable automatic switching of GPIO sleep configuration
I (1552) main_task: Started on CPU0
I (1562) esp_psram: Reserving pool of 32K of internal memory for DMA/internal allocations
I (1562) main_task: Calling app_main()
I (1572) LCD-mipi: i2c_master_init ESP_OK
I (1572) LCD-mipi: tca6408_init...
I (1582) LCD-mipi: sgm37604a_init...
I (1832) LCD-mipi: MIPI DSI LCD initialization
I (1832) LCD-mipi: MIPI DSI PHY Powered on
     0  1  2  3  4  5  6  7  8  9  a  b  c  d  e  f
00: -- -- -- -- -- -- -- -- -- -- -- -- -- -- -- 0f 
10: -- -- -- -- -- -- -- -- -- -- -- -- -- -- -- -- 
20: 20 21 -- -- -- -- -- -- -- -- -- -- -- -- -- -- 
30: -- -- -- -- -- -- 36 -- -- -- -- -- -- -- 3e -- 
40: -- -- -- -- -- -- -- -- -- -- -- -- -- -- -- -- 
50: -- -- 52 -- -- -- -- -- -- -- -- -- -- -- -- -- 
60: -- -- -- -- -- -- -- -- 68 -- -- -- -- -- -- -- 
70: 70 -- -- -- -- -- -- -- -- -- -- -- -- -- -- -- 
I (1872) LCD-mipi: Install MIPI DSI LCD control IO
I (1872) LCD-mipi: Install MIPI DSI LCD data panel
I (1872) LCD-mipi: esp_lcd_new_panel_td4101 panel
I (1902) LCD-mipi: esp_lcd_panel_reset panel
I (2022) LCD-mipi: esp_lcd_panel_init panel
I (2022) td4101: panel_td4101_init called
I (2282) LCD-mipi: Setting test pattern - if you see color bars, MIPI DSI is working
I (5282) LCD-mipi: Initialize LVGL library
I (5282) LCD-mipi: Allocate separate LVGL draw buffers
I (5282) LCD-mipi: Register DPI panel event callback for LVGL flush ready notification
I (5282) LCD-mipi: Use esp_timer as LVGL tick timer
I (5292) LCD-mipi: Create LVGL task
I (5292) LCD-mipi: Starting LVGL task
I (5392) LCD-mipi: Display LVGL Meter Widget
I (5402) main_task: Returned from app_main()
...
```

## Troubleshooting

For any technical queries, please open an [issue](https://github.com/ddB0515/epdInky/issues) on GitHub. We will get back to you soon.

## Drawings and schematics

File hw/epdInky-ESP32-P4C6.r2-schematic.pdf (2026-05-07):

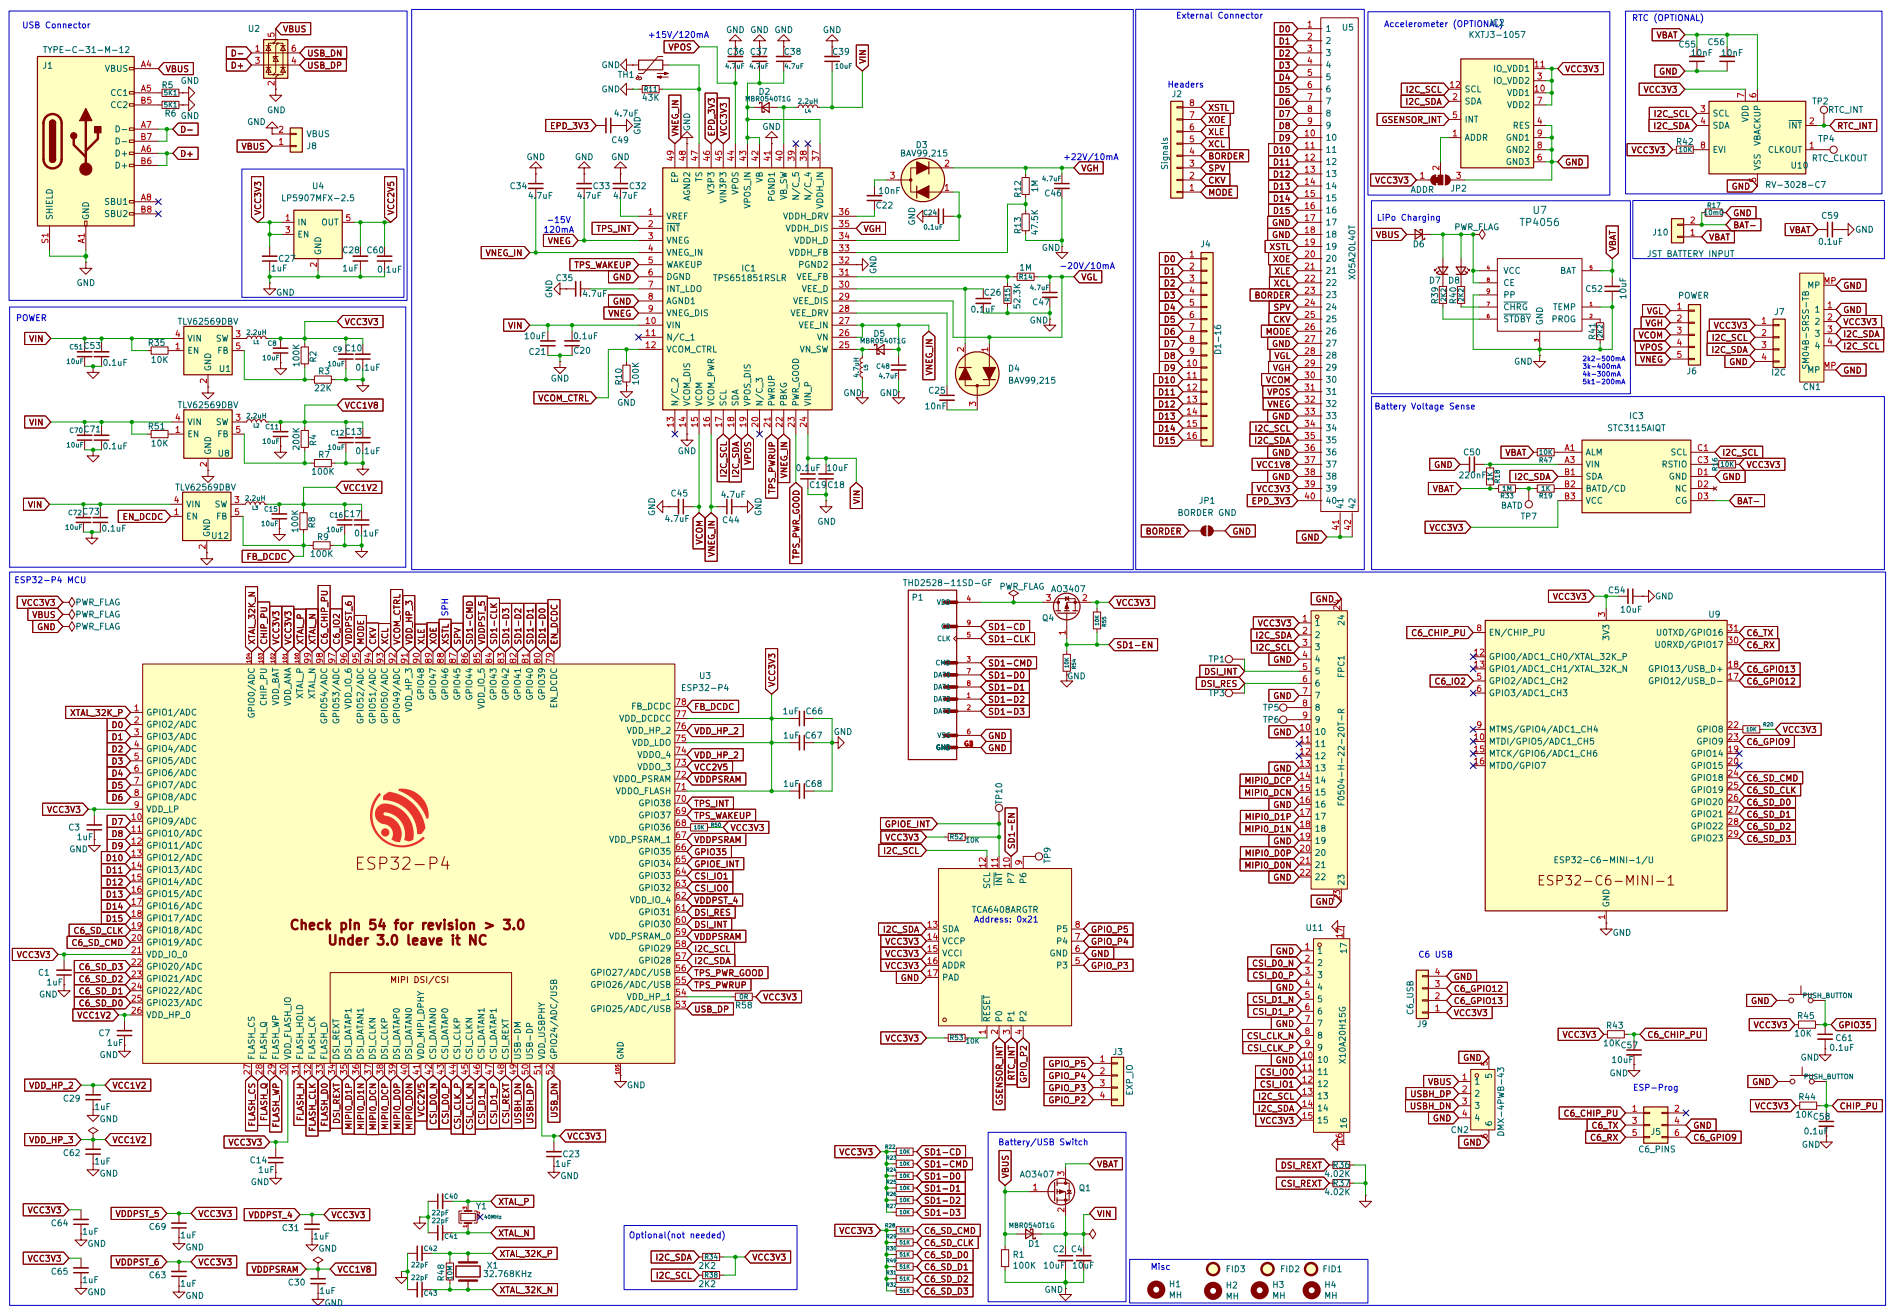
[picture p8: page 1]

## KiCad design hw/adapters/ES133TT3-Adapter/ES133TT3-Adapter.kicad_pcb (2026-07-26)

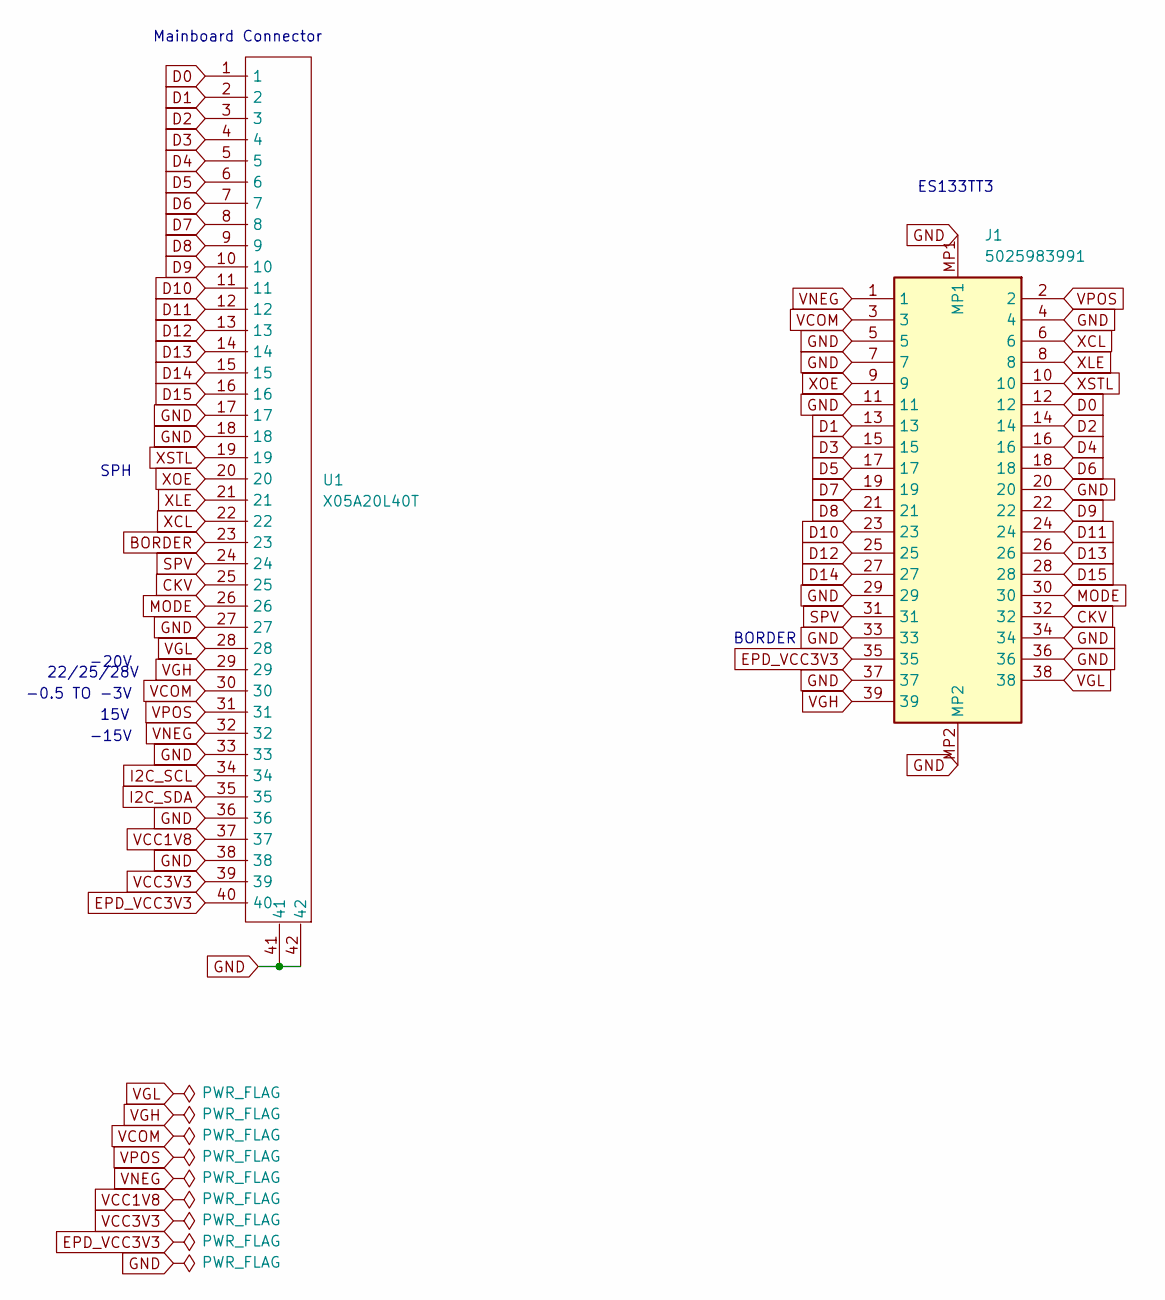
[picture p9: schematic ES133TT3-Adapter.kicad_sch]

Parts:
J1: 5025983991; 5025983993; Mouser Part Number 798-FH2639S0.3SHW05
U1: X05A20L40T; X05A20L40T-2

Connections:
BORDER: U1.23
CKV: J1.32, U1.25
D0: J1.12, U1.1
D1: J1.13, U1.2
D2: J1.14, U1.3
D3: J1.15, U1.4
D4: J1.16, U1.5
D5: J1.17, U1.6
D6: J1.18, U1.7
D7: J1.19, U1.8
D8: J1.21, U1.9
D9: J1.22, U1.10
D10: J1.23, U1.11
D11: J1.24, U1.12
D12: J1.25, U1.13
D13: J1.26, U1.14
D14: J1.27, U1.15
D15: J1.28, U1.16
EPD_VCC3V3: J1.35, U1.40
GND: J1.4, J1.5, J1.7, J1.11, J1.20, J1.29, J1.33, J1.34, J1.36, J1.37, J1.MP1, J1.MP2, U1.17, U1.18, U1.27, U1.33, U1.36, U1.38, U1.41, U1.42
I2C_SCL: U1.34
I2C_SDA: U1.35
MODE: J1.30, U1.26
SPV: J1.31, U1.24
VCC1V8: U1.37
VCC3V3: U1.39
VCOM: J1.3, U1.30
VGH: J1.39, U1.29
VGL: J1.38, U1.28
VNEG: J1.1, U1.32
VPOS: J1.2, U1.31
XCL: J1.6, U1.22
XLE: J1.8, U1.21
XOE: J1.9, U1.20
XSTL: J1.10, U1.19

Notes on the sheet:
-20V
SPH
22/25/28V
15V
BORDER
-15V
ES133TT3
Mainboard Connector
-0.5 TO -3V

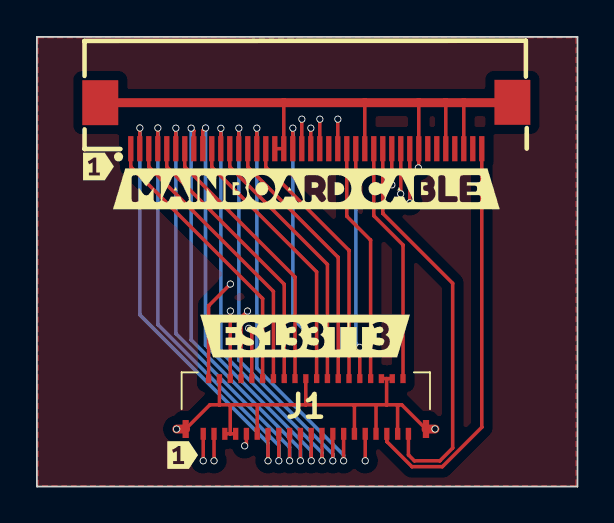
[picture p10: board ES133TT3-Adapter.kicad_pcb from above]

Board: 4 copper layers, 30.0 x 25.0 mm, 6 parts (0 on the bottom side), 30 nets.

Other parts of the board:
kibuzzard-68DD2F05: G***; kibuzzard-68DD2F05
kibuzzard-68DD142E, kibuzzard-68DD142E#2: G***; kibuzzard-68DD142E
kibuzzard-679CBA1D: G***; kibuzzard-679CBA1D

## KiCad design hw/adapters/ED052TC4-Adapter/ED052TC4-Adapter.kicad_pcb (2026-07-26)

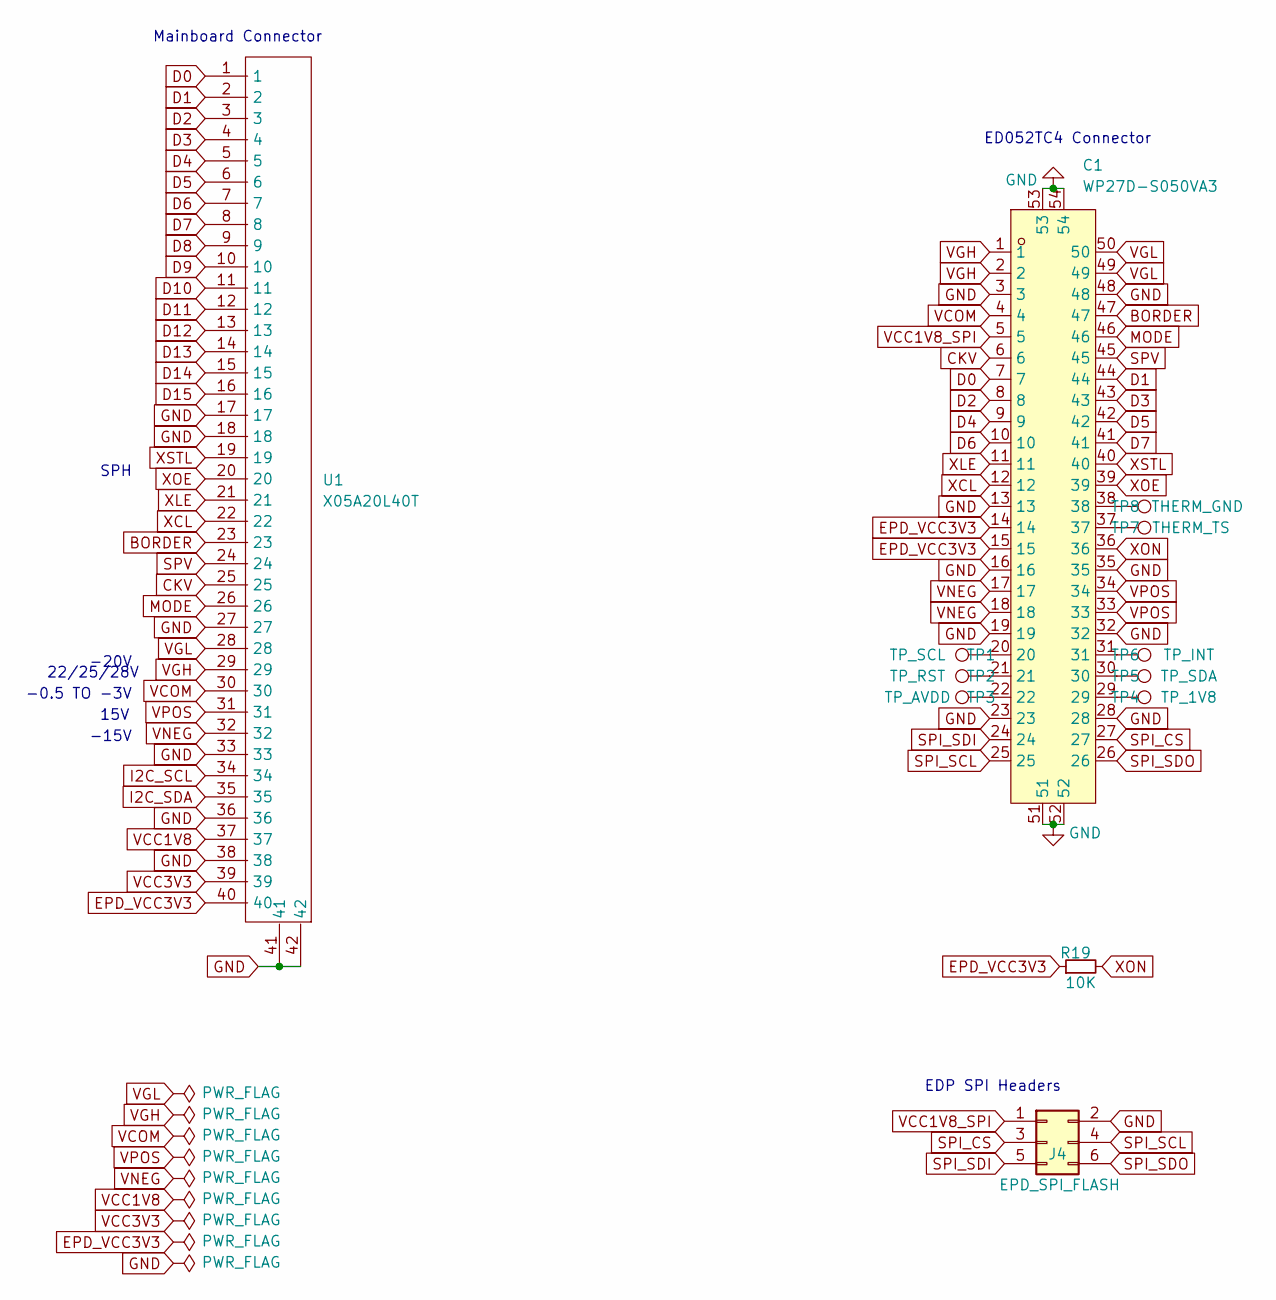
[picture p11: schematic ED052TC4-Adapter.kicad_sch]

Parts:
C1: WP27D-S050VA3; LCSC Part C3640690
J4: EPD_SPI_FLASH; PinHeader_2x03_P1.27mm_Vertical
R19: 10K; R_0603_1608Metric
TP1: TP_SCL; TestPoint_Pad_D1.5mm
TP2: TP_RST; TestPoint_Pad_D1.5mm
TP3: TP_AVDD; TestPoint_Pad_D1.5mm
TP4: TP_1V8; TestPoint_Pad_D1.5mm
TP5: TP_SDA; TestPoint_Pad_D1.5mm
TP6: TP_INT; TestPoint_Pad_D1.5mm
TP7: THERM_TS; TestPoint_Pad_D1.5mm
TP8: THERM_GND; TestPoint_Pad_D1.5mm
U1: X05A20L40T; X05A20L40T-2

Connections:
BORDER: C1.47, U1.23
CKV: C1.6, U1.25
D0: C1.7, U1.1
D1: C1.44, U1.2
D2: C1.8, U1.3
D3: C1.43, U1.4
D4: C1.9, U1.5
D5: C1.42, U1.6
D6: C1.10, U1.7
D7: C1.41, U1.8
D8: U1.9
D9: U1.10
D10: U1.11
D11: U1.12
D12: U1.13
D13: U1.14
D14: U1.15
D15: U1.16
EPD_VCC3V3: C1.14, C1.15, R19.1, U1.40
GND: C1.3, C1.13, C1.16, C1.19, C1.23, C1.28, C1.32, C1.35, C1.48, C1.51, C1.52, C1.53, C1.54, J4.2, U1.17, U1.18, U1.27, U1.33, U1.36, U1.38, U1.41, U1.42
I2C_SCL: U1.34
I2C_SDA: U1.35
MODE: C1.46, U1.26
unnamed: C1.20, TP1.1
unnamed: C1.21, TP2.1
unnamed: C1.22, TP3.1
unnamed: C1.29, TP4.1
unnamed: C1.30, TP5.1
unnamed: C1.31, TP6.1
unnamed: C1.37, TP7.1
unnamed: C1.38, TP8.1
SPI_CS: C1.27, J4.3
SPI_SCL: C1.25, J4.4
SPI_SDI: C1.24, J4.5
SPI_SDO: C1.26, J4.6
SPV: C1.45, U1.24
VCC1V8: U1.37
VCC1V8_SPI: C1.5, J4.1
VCC3V3: U1.39
VCOM: C1.4, U1.30
VGH: C1.1, C1.2, U1.29
VGL: C1.49, C1.50, U1.28
VNEG: C1.17, C1.18, U1.32
VPOS: C1.33, C1.34, U1.31
XCL: C1.12, U1.22
XLE: C1.11, U1.21
XOE: C1.39, U1.20
XON: C1.36, R19.2
XSTL: C1.40, U1.19

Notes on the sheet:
ED052TC4 Connector
-20V
SPH
22/25/28V
15V
-15V
Mainboard Connector
EDP SPI Headers
-0.5 TO -3V

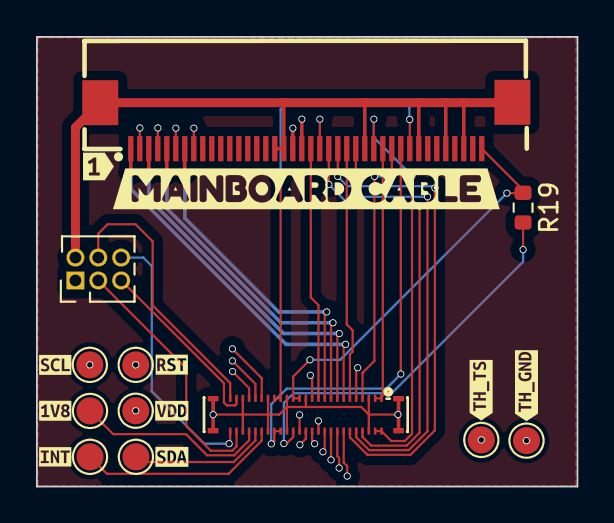
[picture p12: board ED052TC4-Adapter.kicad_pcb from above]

Board: 4 copper layers, 30.0 x 25.0 mm, 22 parts (0 on the bottom side), 37 nets.

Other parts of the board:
kibuzzard-68DD142E: G***; kibuzzard-68DD142E
kibuzzard-679CBA1D: G***; kibuzzard-679CBA1D
kibuzzard-6992F4CA: G***; kibuzzard-6992F4CA
kibuzzard-6992F4E3: G***; kibuzzard-6992F4E3
kibuzzard-6992F4F4: G***; kibuzzard-6992F4F4
kibuzzard-6992F47A: G***; kibuzzard-6992F47A
kibuzzard-6992F480: G***; kibuzzard-6992F480
kibuzzard-6992F502: G***; kibuzzard-6992F502
kibuzzard-6992F518: G***; kibuzzard-6992F518
kibuzzard-6992F521: G***; kibuzzard-6992F521

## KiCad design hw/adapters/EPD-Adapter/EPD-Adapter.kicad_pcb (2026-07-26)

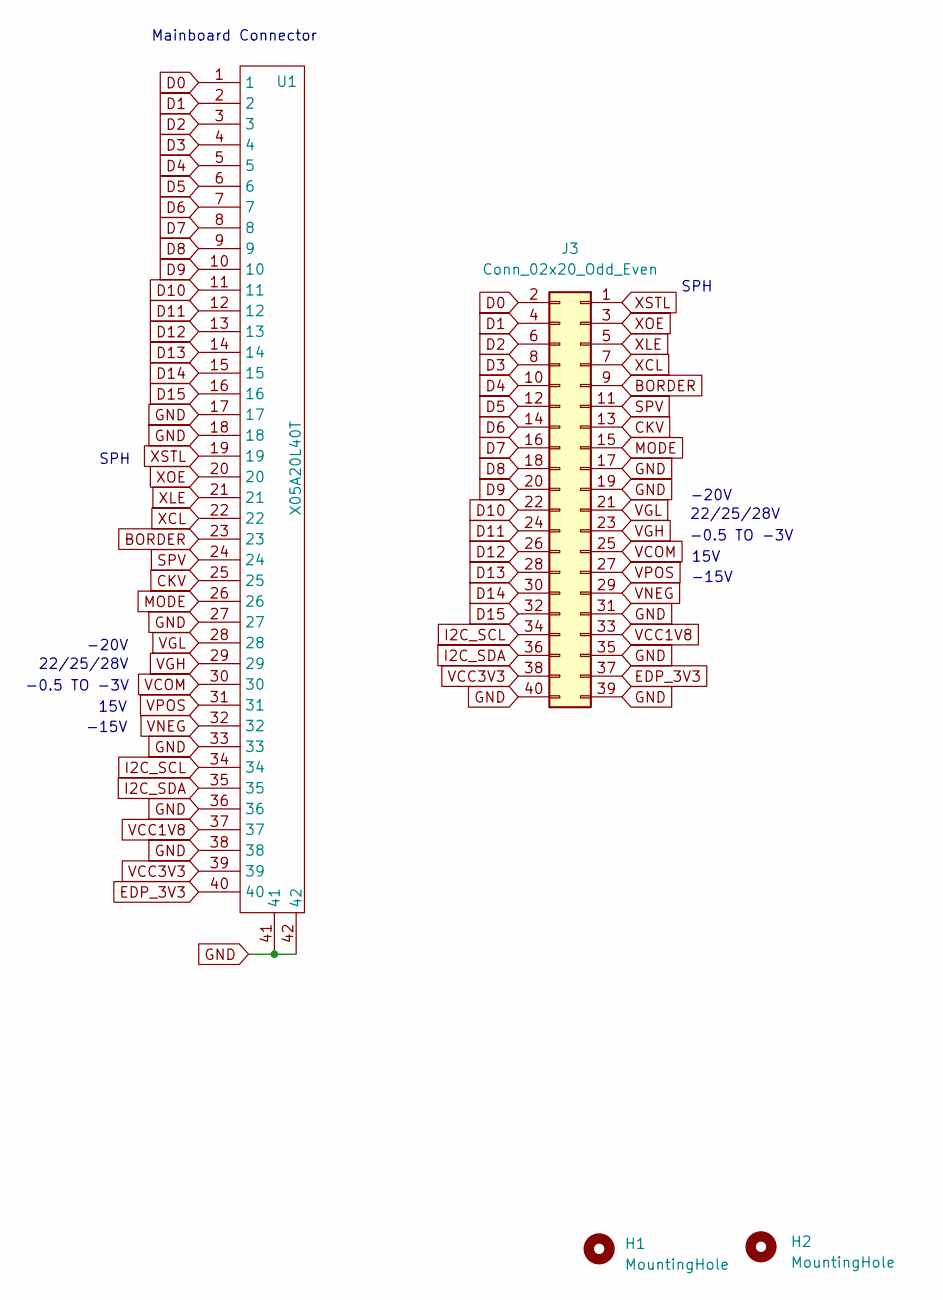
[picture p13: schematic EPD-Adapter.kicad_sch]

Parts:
H1, H2: MountingHole; MountingHole_2.2mm_M2_Pad_Via
J3: Conn_02x20_Odd_Even; PinHeader_2x20_P1.27mm_Vertical_SMD
U1: X05A20L40T; X05A20L40T-2

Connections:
BORDER: J3.9, U1.23
CKV: J3.13, U1.25
D0: J3.2, U1.1
D1: J3.4, U1.2
D2: J3.6, U1.3
D3: J3.8, U1.4
D4: J3.10, U1.5
D5: J3.12, U1.6
D6: J3.14, U1.7
D7: J3.16, U1.8
D8: J3.18, U1.9
D9: J3.20, U1.10
D10: J3.22, U1.11
D11: J3.24, U1.12
D12: J3.26, U1.13
D13: J3.28, U1.14
D14: J3.30, U1.15
D15: J3.32, U1.16
EDP_3V3: J3.37, U1.40
GND: J3.17, J3.19, J3.31, J3.35, J3.39, J3.40, U1.17, U1.18, U1.27, U1.33, U1.36, U1.38, U1.41, U1.42
I2C_SCL: J3.34, U1.34
I2C_SDA: J3.36, U1.35
MODE: J3.15, U1.26
SPV: J3.11, U1.24
VCC1V8: J3.33, U1.37
VCC3V3: J3.38, U1.39
VCOM: J3.25, U1.30
VGH: J3.23, U1.29
VGL: J3.21, U1.28
VNEG: J3.29, U1.32
VPOS: J3.27, U1.31
XCL: J3.7, U1.22
XLE: J3.5, U1.21
XOE: J3.3, U1.20
XSTL: J3.1, U1.19

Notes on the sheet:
15V
-0.5 TO -3V
-20V
-15V
22/25/28V
SPH
Mainboard Connector

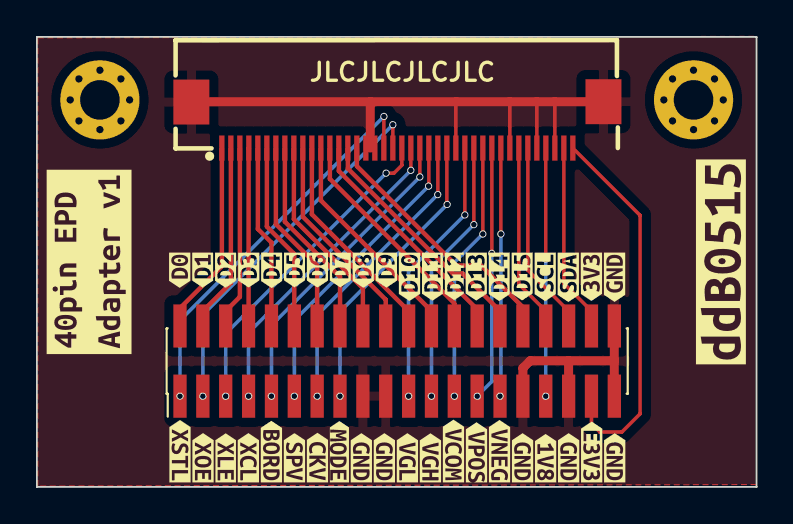
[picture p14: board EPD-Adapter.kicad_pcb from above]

Board: 2 copper layers, 40.0 x 25.0 mm, 46 parts (0 on the bottom side), 35 nets.

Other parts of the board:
kibuzzard-69C13134: G***; kibuzzard-69C13134
kibuzzard-69D687A5: G***; kibuzzard-69D687A5
kibuzzard-69D687BA: G***; kibuzzard-69D687BA
kibuzzard-69D687C8: G***; kibuzzard-69D687C8
kibuzzard-69D687CF: G***; kibuzzard-69D687CF
kibuzzard-69D687D8: G***; kibuzzard-69D687D8
kibuzzard-69D687E0: G***; kibuzzard-69D687E0
kibuzzard-69D687E9: G***; kibuzzard-69D687E9
kibuzzard-69D687F1: G***; kibuzzard-69D687F1
kibuzzard-69D687F8: G***; kibuzzard-69D687F8
kibuzzard-69D688A1: G***; kibuzzard-69D688A1
kibuzzard-69D688A8: G***; kibuzzard-69D688A8
kibuzzard-69D688AE: G***; kibuzzard-69D688AE
kibuzzard-69D688B2: G***; kibuzzard-69D688B2
kibuzzard-69D688B8: G***; kibuzzard-69D688B8
kibuzzard-69D688BD: G***; kibuzzard-69D688BD
kibuzzard-69D688C3: G***; kibuzzard-69D688C3
kibuzzard-69D688D4: G***; kibuzzard-69D688D4
kibuzzard-69D688DA: G***; kibuzzard-69D688DA
kibuzzard-69D688E1: G***; kibuzzard-69D688E1
kibuzzard-69D688E7: G***; kibuzzard-69D688E7
kibuzzard-69D688ED: G***; kibuzzard-69D688ED
kibuzzard-69D688F3: G***; kibuzzard-69D688F3
kibuzzard-69D6879B: G***; kibuzzard-69D6879B
kibuzzard-69D6880A: G***; kibuzzard-69D6880A
kibuzzard-69D6881E: G***; kibuzzard-69D6881E
kibuzzard-69D6887D: G***; kibuzzard-69D6887D
kibuzzard-69D6888B: G***; kibuzzard-69D6888B
kibuzzard-69D68770: G***; kibuzzard-69D68770
kibuzzard-69D68783: G***; kibuzzard-69D68783
kibuzzard-69D68788: G***; kibuzzard-69D68788
kibuzzard-69D68791: G***; kibuzzard-69D68791
kibuzzard-69D68802: G***; kibuzzard-69D68802
kibuzzard-69D68817: G***; kibuzzard-69D68817
kibuzzard-69D68827: G***; kibuzzard-69D68827
kibuzzard-69D68874: G***; kibuzzard-69D68874
kibuzzard-69D68884: G***; kibuzzard-69D68884
kibuzzard-69D68890: G***; kibuzzard-69D68890
kibuzzard-69D68895: G***; kibuzzard-69D68895
kibuzzard-69FC88FD: G***; kibuzzard-69FC88FD
kibuzzard-69FC895D: G***; kibuzzard-69FC895D
kibuzzard-643538E9: G***; kibuzzard-643538E9

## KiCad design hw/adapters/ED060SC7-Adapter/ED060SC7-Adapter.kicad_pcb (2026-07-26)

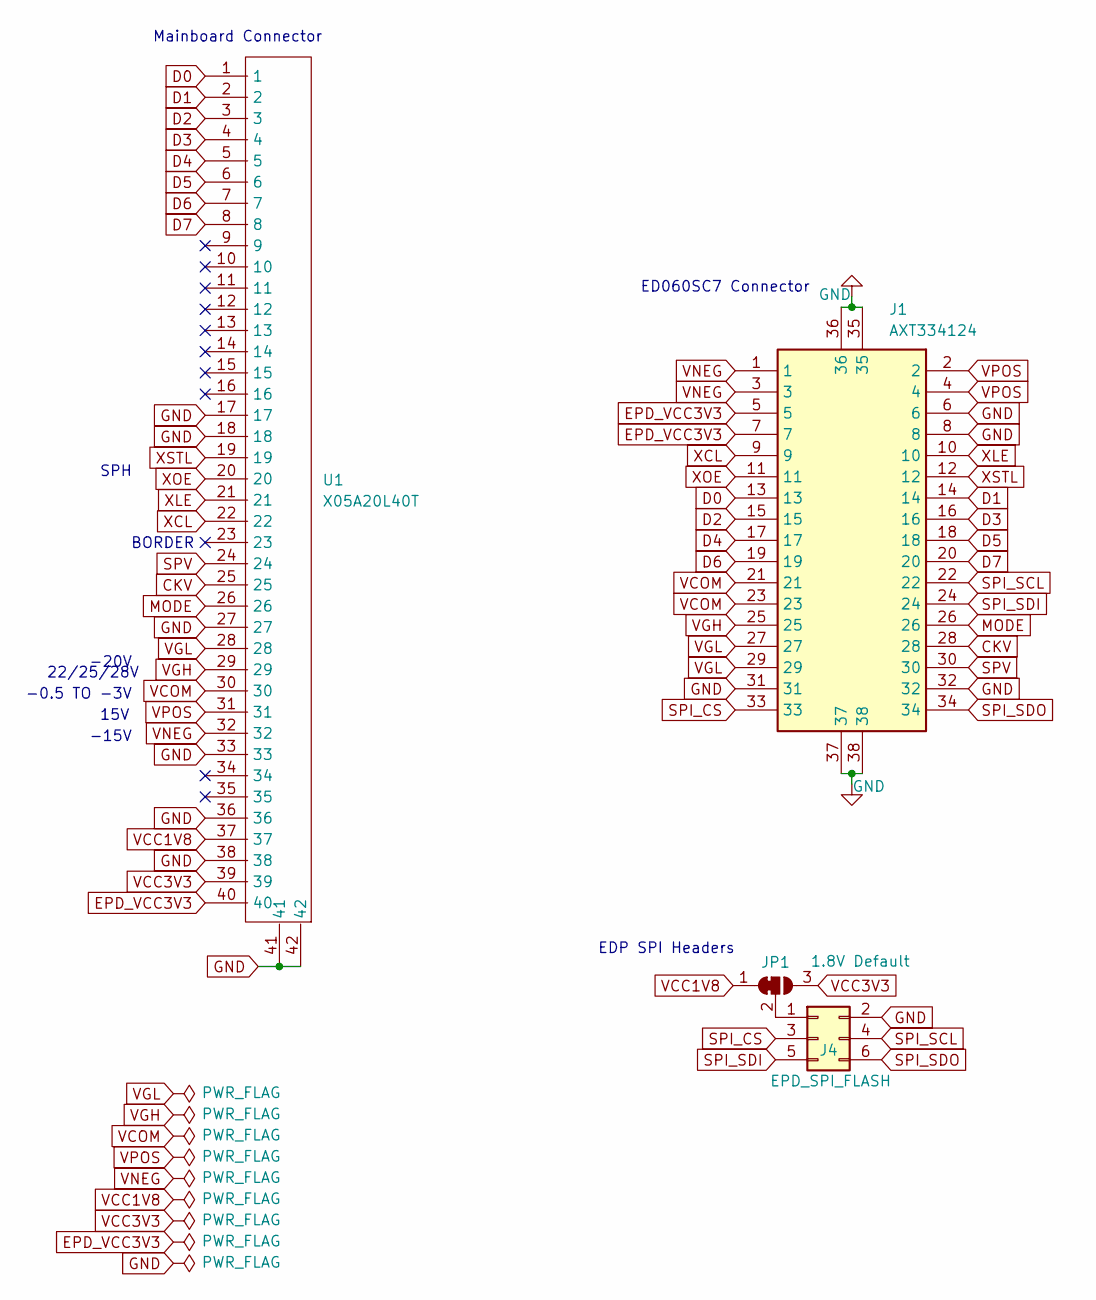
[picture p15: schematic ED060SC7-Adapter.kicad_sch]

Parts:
J1: AXT334124
J4: EPD_SPI_FLASH; PinHeader_2x03_P1.27mm_Vertical
JP1: 1.8V Default; SolderJumper-3_P1.3mm_Bridged12_RoundedPad1.0x1.5mm
U1: X05A20L40T; X05A20L40T-2

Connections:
CKV: J1.28, U1.25
D0: J1.13, U1.1
D1: J1.14, U1.2
D2: J1.15, U1.3
D3: J1.16, U1.4
D4: J1.17, U1.5
D5: J1.18, U1.6
D6: J1.19, U1.7
D7: J1.20, U1.8
EPD_VCC3V3: J1.5, J1.7, U1.40
GND: J1.6, J1.8, J1.31, J1.32, J1.35, J1.36, J1.37, J1.38, J4.2, U1.17, U1.18, U1.27, U1.33, U1.36, U1.38, U1.41, U1.42
MODE: J1.26, U1.26
unnamed: J4.1, JP1.2 (C)
SPI_CS: J1.33, J4.3
SPI_SCL: J1.22, J4.4
SPI_SDI: J1.24, J4.5
SPI_SDO: J1.34, J4.6
SPV: J1.30, U1.24
VCC1V8: JP1.1 (A), U1.37
VCC3V3: JP1.3 (B), U1.39
VCOM: J1.21, J1.23, U1.30
VGH: J1.25, U1.29
VGL: J1.27, J1.29, U1.28
VNEG: J1.1, J1.3, U1.32
VPOS: J1.2, J1.4, U1.31
XCL: J1.9, U1.22
XLE: J1.10, U1.21
XOE: J1.11, U1.20
XSTL: J1.12, U1.19

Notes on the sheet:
-20V
SPH
22/25/28V
EDP SPI Headers
15V
-15V
Mainboard Connector
ED060SC7 Connector
BORDER
-0.5 TO -3V

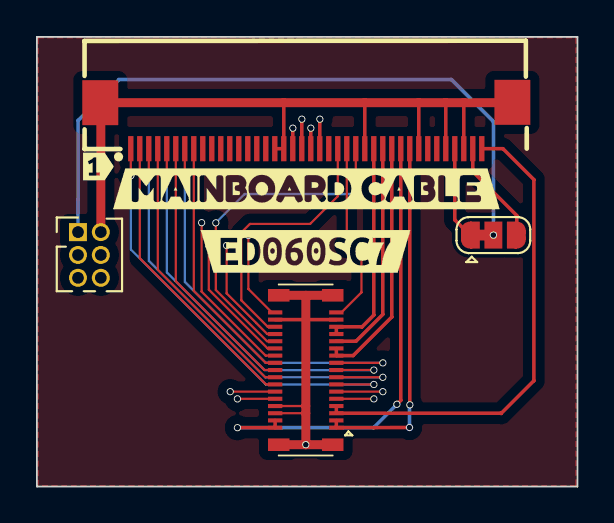
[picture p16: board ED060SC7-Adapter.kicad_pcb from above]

Board: 4 copper layers, 30.0 x 25.0 mm, 7 parts (0 on the bottom side), 29 nets.

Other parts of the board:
kibuzzard-68DD142E: G***; kibuzzard-68DD142E
kibuzzard-68E910D2: G***; kibuzzard-68E910D2
kibuzzard-679CBA1D: G***; kibuzzard-679CBA1D

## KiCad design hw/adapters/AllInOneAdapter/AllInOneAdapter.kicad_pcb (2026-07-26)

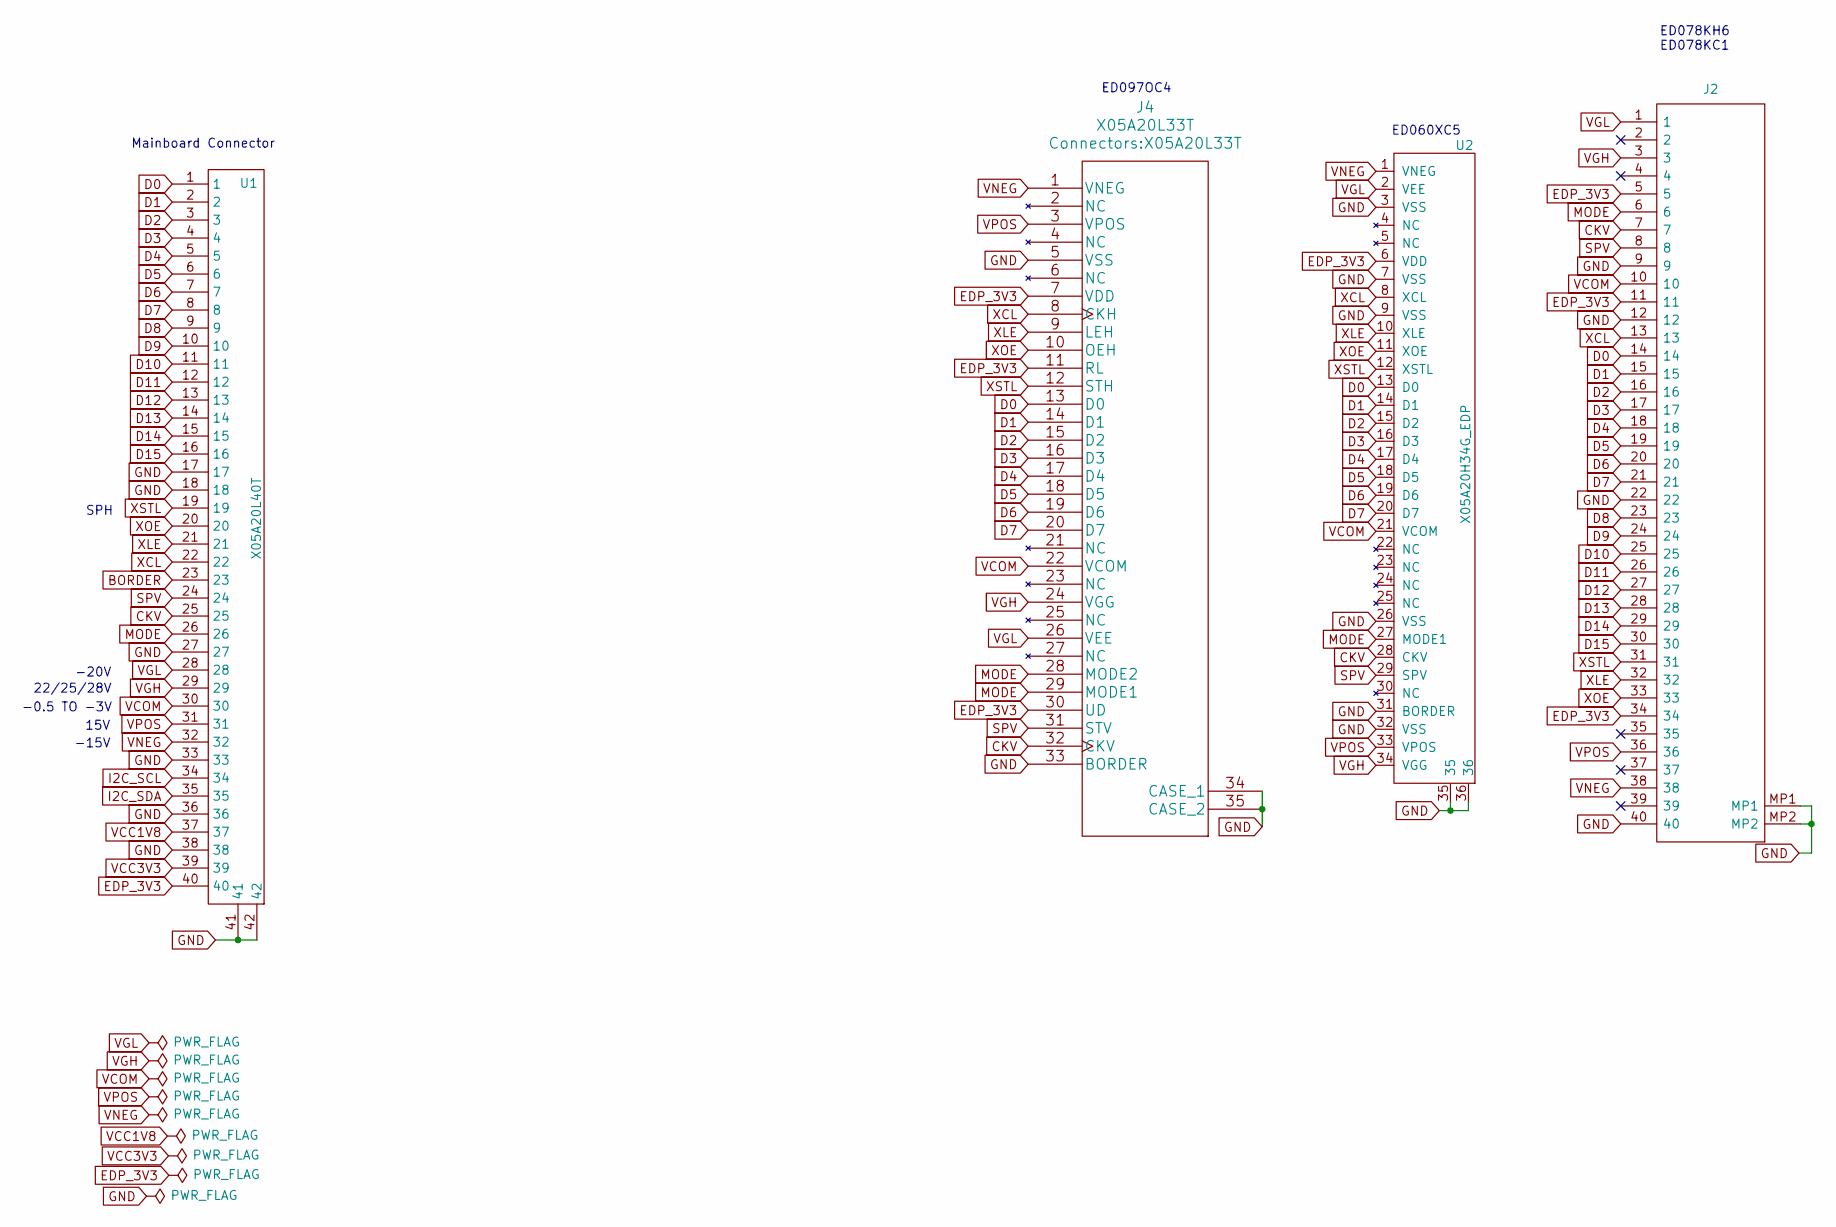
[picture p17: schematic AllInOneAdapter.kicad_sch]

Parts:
J2: FH34SRJ-40S-0.5SH; X05A20L40T; Mouser Part Number 798-FH34SRJ40S05SH50
J4: X05A20L33T; LCSC C2880814
U1: X05A20L40T; X05A20L40T-2
U2: X05A20H34G_EDP; X05A20H34G; LCSC C528053

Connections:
BORDER: U1.23
CKV: J2.7, J4.32 (CKV), U1.25, U2.28 (CKV)
D0: J2.14, J4.13 (D0), U1.1, U2.13 (D0)
D1: J2.15, J4.14 (D1), U1.2, U2.14 (D1)
D2: J2.16, J4.15 (D2), U1.3, U2.15 (D2)
D3: J2.17, J4.16 (D3), U1.4, U2.16 (D3)
D4: J2.18, J4.17 (D4), U1.5, U2.17 (D4)
D5: J2.19, J4.18 (D5), U1.6, U2.18 (D5)
D6: J2.20, J4.19 (D6), U1.7, U2.19 (D6)
D7: J2.21, J4.20 (D7), U1.8, U2.20 (D7)
D8: J2.23, U1.9
D9: J2.24, U1.10
D10: J2.25, U1.11
D11: J2.26, U1.12
D12: J2.27, U1.13
D13: J2.28, U1.14
D14: J2.29, U1.15
D15: J2.30, U1.16
EDP_3V3: J2.5, J2.11, J2.34, J4.7 (VDD), J4.11 (RL), J4.30 (UD), U1.40, U2.6 (VDD)
GND: J2.9, J2.12, J2.22, J2.40, J2.MP1, J2.MP2, J4.5 (VSS), J4.33 (BORDER), J4.34 (CASE_1), J4.35 (CASE_2), U1.17, U1.18, U1.27, U1.33, U1.36, U1.38, U1.41, U1.42, U2.3 (VSS), U2.7 (VSS), U2.9 (VSS), U2.26 (VSS), U2.31 (BORDER), U2.32 (VSS), U2.35, U2.36
I2C_SCL: U1.34
I2C_SDA: U1.35
MODE: J2.6, J4.28 (MODE2), J4.29 (MODE1), U1.26, U2.27 (MODE1)
SPV: J2.8, J4.31 (STV), U1.24, U2.29 (SPV)
VCC1V8: U1.37
VCC3V3: U1.39
VCOM: J2.10, J4.22 (VCOM), U1.30, U2.21 (VCOM)
VGH: J2.3, J4.24 (VGG), U1.29, U2.34 (VGG)
VGL: J2.1, J4.26 (VEE), U1.28, U2.2 (VEE)
VNEG: J2.38, J4.1 (VNEG), U1.32, U2.1 (VNEG)
VPOS: J2.36, J4.3 (VPOS), U1.31, U2.33 (VPOS)
XCL: J2.13, J4.8 (CKH), U1.22, U2.8 (XCL)
XLE: J2.32, J4.9 (LEH), U1.21, U2.10 (XLE)
XOE: J2.33, J4.10 (OEH), U1.20, U2.11 (XOE)
XSTL: J2.31, J4.12 (STH), U1.19, U2.12 (XSTL)

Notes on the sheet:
ED060XC5
-20V
ED078KH6 ED078KC1
SPH
22/25/28V
15V
-15V
Mainboard Connector
ED097OC4
-0.5 TO -3V

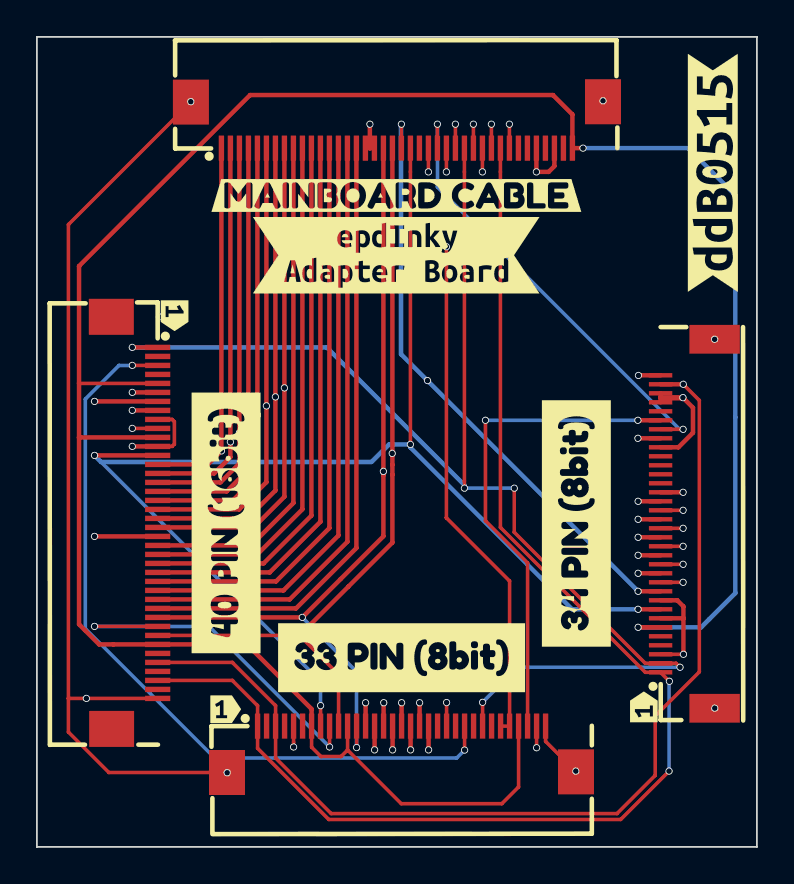
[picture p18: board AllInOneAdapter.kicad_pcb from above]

Board: 4 copper layers, 40.0 x 45.0 mm, 13 parts (0 on the bottom side), 30 nets.

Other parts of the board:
kibuzzard-64EE76F9: G***; kibuzzard-64EE76F9
kibuzzard-69FC73F9, kibuzzard-69FC73F9#2, kibuzzard-69FC73F9#3: G***; kibuzzard-69FC73F9
kibuzzard-69FC745D: G***; kibuzzard-69FC745D
kibuzzard-69FC7454: G***; kibuzzard-69FC7454
kibuzzard-69FC7469: G***; kibuzzard-69FC7469
kibuzzard-69FC7563: G***; kibuzzard-69FC7563
kibuzzard-655FF6E7: G***; kibuzzard-655FF6E7

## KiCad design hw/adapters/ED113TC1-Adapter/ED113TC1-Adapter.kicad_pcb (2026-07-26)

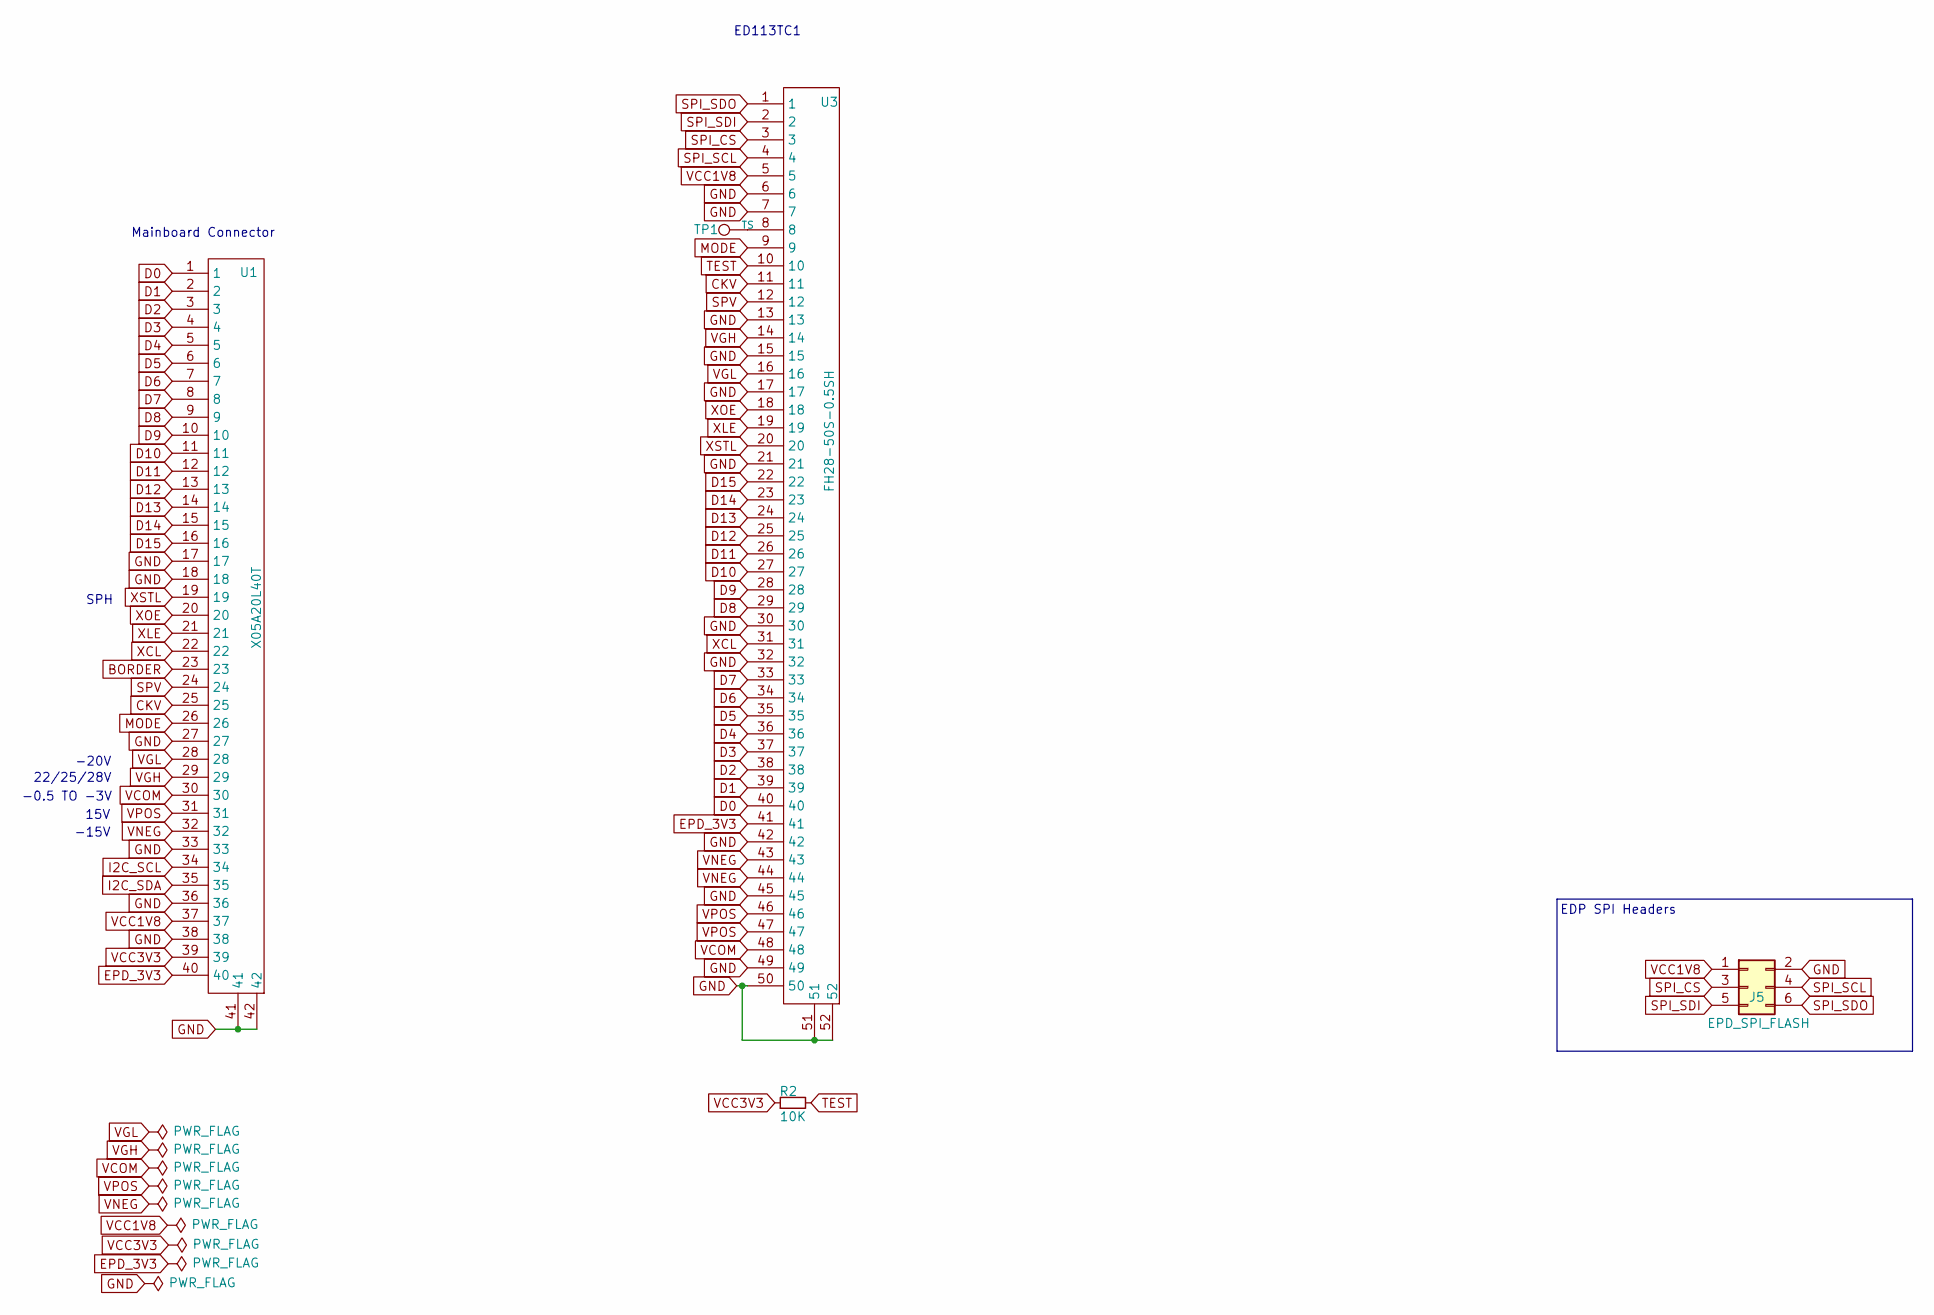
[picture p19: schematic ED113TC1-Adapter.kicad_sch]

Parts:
J5: EPD_SPI_FLASH; PinHeader_2x03_P1.27mm_Vertical
R2: 10K; R_0603_1608Metric
TP1: TS; TestPoint_Pad_D1.5mm
U1: X05A20L40T; X05A20L40T-2
U3: FH28-50S-0.5SH

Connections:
BORDER: U1.23
CKV: U1.25, U3.11
D0: U1.1, U3.40
D1: U1.2, U3.39
D2: U1.3, U3.38
D3: U1.4, U3.37
D4: U1.5, U3.36
D5: U1.6, U3.35
D6: U1.7, U3.34
D7: U1.8, U3.33
D8: U1.9, U3.29
D9: U1.10, U3.28
D10: U1.11, U3.27
D11: U1.12, U3.26
D12: U1.13, U3.25
D13: U1.14, U3.24
D14: U1.15, U3.23
D15: U1.16, U3.22
EPD_3V3: U1.40, U3.41
GND: J5.2, U1.17, U1.18, U1.27, U1.33, U1.36, U1.38, U1.41, U1.42, U3.6, U3.7, U3.13, U3.15, U3.17, U3.21, U3.30, U3.32, U3.42, U3.45, U3.49, U3.50, U3.51, U3.52
I2C_SCL: U1.34
I2C_SDA: U1.35
MODE: U1.26, U3.9
unnamed: TP1.1, U3.8
SPI_CS: J5.3, U3.3
SPI_SCL: J5.4, U3.4
SPI_SDI: J5.5, U3.2
SPI_SDO: J5.6, U3.1
SPV: U1.24, U3.12
TEST: R2.2, U3.10
VCC1V8: J5.1, U1.37, U3.5
VCC3V3: R2.1, U1.39
VCOM: U1.30, U3.48
VGH: U1.29, U3.14
VGL: U1.28, U3.16
VNEG: U1.32, U3.43, U3.44
VPOS: U1.31, U3.46, U3.47
XCL: U1.22, U3.31
XLE: U1.21, U3.19
XOE: U1.20, U3.18
XSTL: U1.19, U3.20

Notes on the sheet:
-20V
EDP SPI Headers
SPH
22/25/28V
15V
-15V
Mainboard Connector
ED113TC1
-0.5 TO -3V

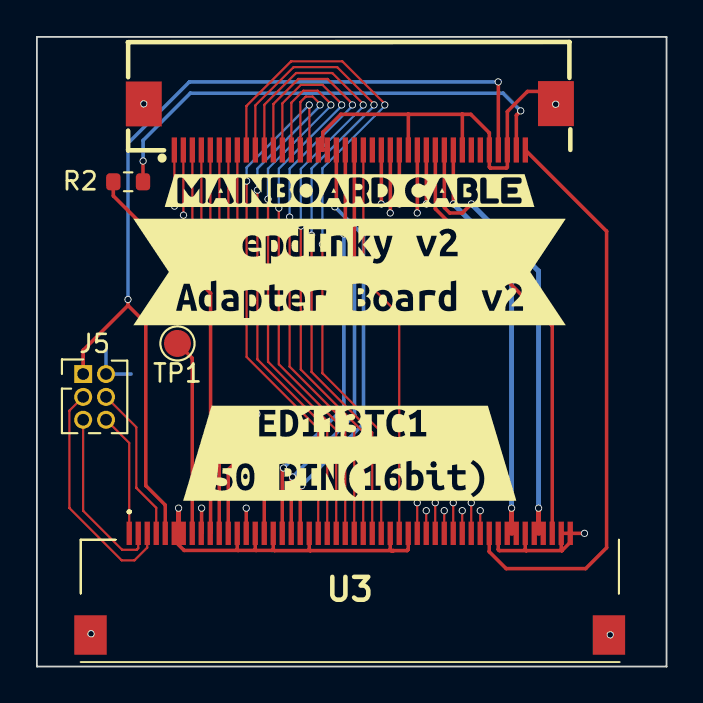
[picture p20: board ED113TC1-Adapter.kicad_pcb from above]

Board: 4 copper layers, 35.0 x 35.0 mm, 8 parts (0 on the bottom side), 38 nets.

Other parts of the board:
kibuzzard-655FF6E7: G***; kibuzzard-655FF6E7
kibuzzard-65609A2F: G***; kibuzzard-65609A2F
kibuzzard-683734A7: G***; kibuzzard-683734A7

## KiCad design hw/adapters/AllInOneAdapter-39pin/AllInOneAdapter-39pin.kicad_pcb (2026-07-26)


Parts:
J1, J2, J3: FH26-39S-0.3SHW; FH2639S03SHW; Mouser Part Number 798-FH2639S0.3SHW05
JP1: LED SELECTION; SolderJumper-3_P1.3mm_Open_RoundedPad1.0x1.5mm
U1: X05A20L40T; X05A20L40T-2
U2: AP2281-3WG-7; SOT26

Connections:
BORDER: U1.23
CKV: J1.33, J2.33, J3.33, J3.38, U1.25
D0: J1.12, J2.12, J3.12, U1.1
D1: J1.13, J2.13, J3.13, U1.2
D2: J1.14, J2.14, J3.14, U1.3
D3: J1.15, J2.15, J3.15, U1.4
D4: J1.16, J2.16, J3.16, U1.5
D5: J1.17, J2.17, J3.17, U1.6
D6: J1.18, J2.18, J3.18, U1.7
D7: J1.19, J2.19, J3.19, U1.8
D8: U1.9
D9: U1.10
D10: U1.11
D11: U1.12
D12: U1.13
D13: U1.14
D14: U1.15
D15: JP1.1 (A), U1.16
EPD_VCC3V3: J1.4, J2.4, J3.4, J3.8, J3.10, J3.29, J3.30, J3.35, J3.36, U1.40
GND: J1.3, J1.8, J1.9, J1.20, J1.29, J1.30, J1.31, J1.34, J1.35, J1.36, J1.37, J1.38, J1.39, J1.MP1, J1.MP2, J2.3, J2.34, J2.39, J2.MP1, J2.MP2, J3.3, J3.9, J3.31, J3.34, J3.MP1, J3.MP2, U1.17, U1.18, U1.27, U1.33, U1.36, U1.38, U1.41, U1.42, U2.2 (GND), U2.5 (GND)
I2C_SCL: U1.34
I2C_SDA: U1.35
LED+: J2.37, U2.1 (OUT)
MODE: J1.28, J2.27, J2.28, J3.27, J3.28, U1.26
unnamed: JP1.2 (C), U2.3 (EN)
SPV: J1.32, J2.32, J3.32, J3.37, U1.24
VCC1V8: U1.37
VCC3V3: JP1.3 (B), U1.39, U2.4 (IN), U2.6 (IN)
VCOM: J1.22, J2.22, J3.22, U1.30
VGH: J1.23, J2.23, J3.23, U1.29
VGL: J1.24, J2.24, J3.24, U1.28
VNEG: J1.1, J2.1, J3.1, U1.32
VPOS: J1.2, J2.2, J3.2, U1.31
XCL: J1.5, J2.5, J3.5, U1.22
XLE: J1.6, J2.6, J3.6, U1.21
XOE: J1.7, J2.7, J3.7, U1.20
XSTL: J1.11, J2.11, J3.11, U1.19

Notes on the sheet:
-20V
BORDER
SPH
22/25/28V
15V
ET017QG1
-15V
ED133UT2
Mainboard Connector
ED060SC4
-0.5 TO -3V


Board: 4 copper layers, 40.0 x 45.0 mm, 11 parts (0 on the bottom side), 26 nets.

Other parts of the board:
kibuzzard-679CBA1D: G***; kibuzzard-679CBA1D
kibuzzard-679CBA3C: G***; kibuzzard-679CBA3C
kibuzzard-679CBA31: G***; kibuzzard-679CBA31
kibuzzard-679CBA36: G***; kibuzzard-679CBA36
kibuzzard-68373226: G***; kibuzzard-68373226

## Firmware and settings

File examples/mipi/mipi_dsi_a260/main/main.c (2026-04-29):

#include <stdio.h>
#include <stdlib.h>
#include <string.h>
#include <unistd.h>
#include <sys/lock.h>
#include "sdkconfig.h"
#include "freertos/FreeRTOS.h"
#include "freertos/task.h"
#include "freertos/semphr.h"
#include "esp_timer.h"
#include "esp_lcd_panel_ops.h"
#include "esp_lcd_mipi_dsi.h"
#include "esp_ldo_regulator.h"
#include "esp_vfs_fat.h"
#include "sdmmc_cmd.h"
#include "driver/sdmmc_host.h"
#include "driver/gpio.h"
#include "driver/ppa.h"
#include "driver/i2c_master.h"
#include "esp_err.h"
#include "esp_log.h"
#include "esp_cache.h"
#include "esp_heap_caps.h"
#include "esp_private/esp_cache_private.h"
#include "lvgl.h"
#include "main.h" 

static const char *TAG = "LCD-mipi";

////////////////////////////////////////////////////////////////////////////////////////////////////////////////////////
//////////////////// Please update the following configuration according to your LCD Spec //////////////////////////////
////////////////////////////////////////////////////////////////////////////////////////////////////////////////////////


// Refresh Rate = 33670000/(480+20+30+30)/(960+2+20+20) = 60.00Hz
#define EXAMPLE_MIPI_DSI_DPI_CLK_MHZ  60
#define EXAMPLE_MIPI_DSI_LCD_H_RES    540
#define EXAMPLE_MIPI_DSI_LCD_V_RES    960
#define EXAMPLE_MIPI_DSI_LCD_HSYNC    4
#define EXAMPLE_MIPI_DSI_LCD_HBP      40
#define EXAMPLE_MIPI_DSI_LCD_HFP      364
#define EXAMPLE_MIPI_DSI_LCD_VSYNC    2
#define EXAMPLE_MIPI_DSI_LCD_VBP      13
#define EXAMPLE_MIPI_DSI_LCD_VFP      244

// The "VDD_MIPI_DPHY" should be supplied with 2.5V, it can source from the internal LDO regulator or from external LDO chip
#define EXAMPLE_MIPI_DSI_PHY_PWR_LDO_CHAN       3  // LDO_VO3 is connected to VDD_MIPI_DPHY
#define EXAMPLE_MIPI_DSI_PHY_PWR_LDO_VOLTAGE_MV 2500
#define EXAMPLE_LCD_BK_LIGHT_ON_LEVEL           true
#define EXAMPLE_LCD_BK_LIGHT_OFF_LEVEL          !EXAMPLE_LCD_BK_LIGHT_ON_LEVEL
#define EXAMPLE_PIN_NUM_BK_LIGHT                -1
#define EXAMPLE_PIN_NUM_LCD_RST                 -1


////////////////////////////////////////////////////////////////////////////////////////////////////////////////////////
//////////////////// Please update the following configuration according to your Application ///////////////////////////
////////////////////////////////////////////////////////////////////////////////////////////////////////////////////////

#define EXAMPLE_LVGL_DRAW_BUF_LINES    (EXAMPLE_MIPI_DSI_LCD_V_RES / 10) // number of display lines in each draw buffer
#define EXAMPLE_LVGL_TICK_PERIOD_MS    2
#define EXAMPLE_LVGL_TASK_STACK_SIZE   (4 * 1024)
#define EXAMPLE_LVGL_TASK_PRIORITY     2

////////////////////////////////////////////
//////////// I2C EXPANDER //////////////////
////////////////////////////////////////////
#define I2C_MASTER_SCL_IO           29      /*!< GPIO number for I2C master clock */
#define I2C_MASTER_SDA_IO           28      /*!< GPIO number for I2C master data  */
#define I2C_MASTER_NUM              I2C_NUM_0 /*!< I2C master i2c port number */
#define I2C_MASTER_FREQ_HZ          400000 /*!< I2C master clock frequency */
#define I2C_MASTER_TX_BUF_DISABLE   0      /*!< I2C master doesn't need buffer */
#define I2C_MASTER_RX_BUF_DISABLE   0      /*!< I2C master doesn't need buffer */
#define I2C_MASTER_TIMEOUT_MS       1000

#define TPS65132_ADDR 0x3E
#define TPS65132_CLK_SPEED 400000

#define MOUNT_POINT "/sdcard"
static const char *file_hello = MOUNT_POINT"/stc3115.txt";

i2c_master_bus_handle_t i2c_bus_handle = NULL;
i2c_master_dev_handle_t tps65132_dev_handle = NULL;

tca6408_handle_t tca_board = NULL;
tca6408_handle_t tca_display = NULL;
stc3115_handle_t stc3115_dev = NULL;

static esp_err_t i2c_master_init(void) {
    // Configure the I2C bus
    i2c_master_bus_config_t bus_config = {
        .i2c_port = I2C_MASTER_NUM,           // Your existing I2C_NUM_0
        .sda_io_num = I2C_MASTER_SDA_IO,      // Your existing SDA pin
        .scl_io_num = I2C_MASTER_SCL_IO,      // Your existing SCL pin
        .clk_source = I2C_CLK_SRC_DEFAULT,    // Use default clock source
        .glitch_ignore_cnt = 100,             // Filter out glitches < 350ns
        .flags.enable_internal_pullup = true, // Equivalent to your pullup enables
    };

    // Initialize the bus and get handle
    esp_err_t err = i2c_new_master_bus(&bus_config, &i2c_bus_handle);
    if (err != ESP_OK) {
        ESP_LOGE(TAG, "Failed to initialize I2C bus: %s", esp_err_to_name(err));
        return err;
    }
    ESP_LOGI(TAG, "i2c_master_init ESP_OK");
    return ESP_OK;
}

// LVGL library is not thread-safe, this example will call LVGL APIs from different tasks, so use a mutex to protect it
static _lock_t lvgl_api_lock;

extern void example_lvgl_demo_ui(lv_display_t *disp);

static void example_lvgl_flush_cb(lv_display_t *disp, const lv_area_t *area, uint8_t *px_map)
{
    esp_lcd_panel_handle_t panel_handle = lv_display_get_user_data(disp);
    int offsetx1 = area->x1;
    int offsetx2 = area->x2;
    int offsety1 = area->y1;
    int offsety2 = area->y2;
    // pass the draw buffer to the driver
    esp_lcd_panel_draw_bitmap(panel_handle, offsetx1, offsety1, offsetx2 + 1, offsety2 + 1, px_map);
}

static void example_increase_lvgl_tick(void *arg)
{
    /* Tell LVGL how many milliseconds has elapsed */
    lv_tick_inc(EXAMPLE_LVGL_TICK_PERIOD_MS);
}

static void example_lvgl_port_task(void *arg)
{
    ESP_LOGI(TAG, "Starting LVGL task");
    uint32_t time_till_next_ms = 0;
    while (1) {
        _lock_acquire(&lvgl_api_lock);
        time_till_next_ms = lv_timer_handler();
        _lock_release(&lvgl_api_lock);

        // in case of task watch dog timeout, set the minimal delay to 10ms
        if (time_till_next_ms < 10) {
            time_till_next_ms = 10;
        }
        usleep(1000 * time_till_next_ms);
    }
}

static bool example_notify_lvgl_flush_ready(esp_lcd_panel_handle_t panel, esp_lcd_dpi_panel_event_data_t *edata, void *user_ctx)
{
    lv_display_t *disp = (lv_display_t *)user_ctx;
    lv_display_flush_ready(disp);
    return false;
}

static void example_bsp_enable_dsi_phy_power(void)
{
    // Turn on the power for MIPI DSI PHY, so it can go from "No Power" state to "Shutdown" state
    esp_ldo_channel_handle_t ldo_mipi_phy = NULL;
#ifdef EXAMPLE_MIPI_DSI_PHY_PWR_LDO_CHAN
    esp_ldo_channel_config_t ldo_mipi_phy_config = {
        .chan_id = EXAMPLE_MIPI_DSI_PHY_PWR_LDO_CHAN,
        .voltage_mv = EXAMPLE_MIPI_DSI_PHY_PWR_LDO_VOLTAGE_MV,
    };
    ESP_ERROR_CHECK(esp_ldo_acquire_channel(&ldo_mipi_phy_config, &ldo_mipi_phy));
    ESP_LOGI(TAG, "MIPI DSI PHY Powered on");
#endif
}

static void example_bsp_init_lcd_backlight(void) {
    // Enable backlight 1st
    tca6408_set_output_pin(tca_display, 3, 1); // Set pin 3 high // PWM_EN
    // Initialize the backlight driver
    sgm37604a_init();
}

static void example_bsp_set_lcd_backlight(uint32_t level) {
    sgm37604a_set_brightness_level(64);
    sgm37604a_backlight(true);
}


void gpio_init(void) {
    // 1. Configure GPIO 26 as Output
    gpio_config_t io_conf_output = {};
    io_conf_output.pin_bit_mask = (1ULL << GPIO_NUM_26); // Select GPIO 26
    io_conf_output.mode = GPIO_MODE_OUTPUT;              // Set as output
    io_conf_output.intr_type = GPIO_INTR_DISABLE;        // Disable interrupt
    io_conf_output.pull_down_en = 0;                     // Disable pull-down
    io_conf_output.pull_up_en = 0;                       // Disable pull-up
    gpio_config(&io_conf_output);

    gpio_config_t io_conf_input_tp_int = {};
    io_conf_input_tp_int.pin_bit_mask = (1ULL << GPIO_NUM_30); // Select GPIO 26
    io_conf_input_tp_int.mode = GPIO_MODE_OUTPUT;              // Set as output
    io_conf_input_tp_int.intr_type = GPIO_INTR_DISABLE;        // Disable interrupt
    io_conf_input_tp_int.pull_down_en = 0;                     // Disable pull-down
    io_conf_input_tp_int.pull_up_en = 0;                       // Disable pull-up
    gpio_config(&io_conf_input_tp_int);

    gpio_config_t io_conf_output_tp_res = {};
    io_conf_output_tp_res.pin_bit_mask = (1ULL << GPIO_NUM_31); // Select GPIO 26
    io_conf_output_tp_res.mode = GPIO_MODE_OUTPUT;              // Set as output
    io_conf_output_tp_res.intr_type = GPIO_INTR_DISABLE;        // Disable interrupt
    io_conf_output_tp_res.pull_down_en = 0;                     // Disable pull-down
    io_conf_output_tp_res.pull_up_en = 0;                       // Disable pull-up
    gpio_config(&io_conf_output_tp_res);

    gpio_config_t io_conf_output2 = {};
    io_conf_output2.pin_bit_mask = (1ULL << GPIO_NUM_37); // Select GPIO 37
    io_conf_output2.mode = GPIO_MODE_OUTPUT;              // Set as output
    io_conf_output2.intr_type = GPIO_INTR_DISABLE;        // Disable interrupt
    io_conf_output2.pull_down_en = 0;                     // Disable pull-down
    io_conf_output2.pull_up_en = 0;                       // Disable pull-up
    gpio_config(&io_conf_output2);

    gpio_config_t io_conf_output3 = {};
    io_conf_output3.pin_bit_mask = (1ULL << GPIO_NUM_49); // Select GPIO 49
    io_conf_output3.mode = GPIO_MODE_OUTPUT;              // Set as output
    io_conf_output3.intr_type = GPIO_INTR_DISABLE;        // Disable interrupt
    io_conf_output3.pull_down_en = 0;                     // Disable pull-down
    io_conf_output3.pull_up_en = 0;                       // Disable pull-up
    gpio_config(&io_conf_output3);

    // 2. Configure GPIO 27 as Input
    gpio_config_t io_conf_input = {};
    io_conf_input.pin_bit_mask = (1ULL << GPIO_NUM_27);  // Select GPIO 27
    io_conf_input.mode = GPIO_MODE_INPUT;                // Set as input
    io_conf_input.intr_type = GPIO_INTR_DISABLE;         // Disable interrupt
    // Choose pull mode (optional, but often needed for inputs):
    io_conf_input.pull_up_en = 1;    // Enable internal pull-up resistor
    io_conf_input.pull_down_en = 0;  // Disable pull-down
    gpio_config(&io_conf_input);
}

/**
 * @brief Scan for I2C devices
 */
void i2c_scan_devices(void)
{
    uint8_t address, devices_found;
    printf("     0  1  2  3  4  5  6  7  8  9  a  b  c  d  e  f\r\n");
    for (int i = 0; i < 128; i += 16) {
        printf("%02x: ", i);
        for (int j = 0; j < 16; j++) {
            fflush(stdout);
            address = i + j;
            esp_err_t ret = i2c_master_probe(i2c_bus_handle, address, -1);
            if (ret == ESP_OK) {
                printf("%02x ", address);
                devices_found++;
            } else if (ret == ESP_ERR_TIMEOUT) {
                printf("UU ");
            } else {
                printf("-- ");
            }
        }
        printf("\r\n");
    }
}

esp_err_t tps65132_i2c_init(i2c_master_bus_handle_t bus_handle) {
    
    i2c_device_config_t dev_cfg = {
        .dev_addr_length = I2C_ADDR_BIT_LEN_7,
        .device_address = TPS65132_ADDR,
        .scl_speed_hz = TPS65132_CLK_SPEED,
    };

    esp_err_t ret = i2c_master_bus_add_device(bus_handle, &dev_cfg, &tps65132_dev_handle);
    if (ret != ESP_OK) {
        ESP_LOGE(TAG, "Failed to add I2C device: %s", esp_err_to_name(ret));
        return ret;
    }
    
    return ESP_OK;
}

static esp_err_t tps65132_write_register(uint8_t reg, uint8_t value) {
    uint8_t write_buf[2] = {reg, value};
    return i2c_master_transmit(tps65132_dev_handle, write_buf, sizeof(write_buf), -1);
}


// Task function
void brightness_task(void *pvParameters) {
    int value = 10;
    while (1) {
        printf("Brightness set to: %d\n", value);
        sgm37604a_set_brightness_level(value);

        value+=10;
        if (value > 255) {
            value = 0; // loop back to 0
        }

        vTaskDelay(pdMS_TO_TICKS(1000)); // wait 
    }
}

void app_main(void)
{
    gpio_init();
    gpio_set_level(GPIO_NUM_26, 1); // Set HIGH
    gpio_set_level(GPIO_NUM_37, 1); // Set HIGH
    gpio_set_level(GPIO_NUM_49, 1); // Set HIGH
    gpio_set_level(GPIO_NUM_31, 1); // Set HIGH (LCD_RES)


    i2c_master_init();

    ESP_LOGI(TAG, "tca6408_init...");

    if (tca6408_init(i2c_bus_handle, 0x21, &tca_board) != ESP_OK) {
        ESP_LOGE(TAG, "Failed to initialize TCA6408 at 0x20");
    }
    tca6408_set_config(tca_board, 0x00); // All pins as output
    tca6408_set_output_val(tca_board, 0x00); // Set all pins low
    tca6408_set_output_pin(tca_board, 7, 0); // Set pin SDCARD low to enable

    if (tca6408_init(i2c_bus_handle, 0x20, &tca_display) != ESP_OK) {
        ESP_LOGE(TAG, "Failed to initialize TCA6408 at 0x21");
    }

    tca6408_set_config(tca_display, 0x00); // All pins as output
    tca6408_set_output_val(tca_display, 0x00); // Set all pins low

    tca6408_set_output_pin(tca_display, 0, 1); // Set pin 0 high // GPIO_EN
    tca6408_set_output_pin(tca_display, 1, 1); // Set pin 2 high // LCD BIAS EN
    tca6408_set_output_pin(tca_display, 2, 1); // Set pin 2 high // BL_EN


    if (tps65132_i2c_init(i2c_bus_handle) != ESP_OK) {
        ESP_LOGE(TAG, "Failed to initialize tps65132");
    }
    // This needs to be run only once (didn't implement check if is already initialized)
    // // Set +5.9V
    // tps65132_write_register(0x00, 0x13);
    // // Set -5.9V
    // tps65132_write_register(0x01, 0x13);
    // vTaskDelay(pdMS_TO_TICKS(5));
    // tps65132_write_register(0xff, 0x80);
    // vTaskDelay(pdMS_TO_TICKS(5));
    // // Enable AVDD and AVEE
    // tps65132_write_register(0x03, 0x03);
    // vTaskDelay(pdMS_TO_TICKS(10));

    delay(10);   

    ESP_LOGI(TAG, "sgm37604a_init...");
    if (sgm37604a_i2c_init(i2c_bus_handle) != ESP_OK) {
        ESP_LOGE("MAIN", "Failed to initialize I2C");
        return;
    }

    delay(250);

    ESP_LOGI(TAG, "MIPI DSI LCD initialization");
    example_bsp_enable_dsi_phy_power();
    example_bsp_init_lcd_backlight();
    example_bsp_set_lcd_backlight(EXAMPLE_LCD_BK_LIGHT_OFF_LEVEL);

    i2c_scan_devices();

    // create MIPI DSI bus first, it will initialize the DSI PHY as well
    esp_lcd_dsi_bus_handle_t mipi_dsi_bus = NULL;
    esp_lcd_dsi_bus_config_t bus_config = TD4101_PANEL_BUS_DSI_2CH_CONFIG();
    ESP_ERROR_CHECK(esp_lcd_new_dsi_bus(&bus_config, &mipi_dsi_bus));

    ESP_LOGI(TAG, "Install MIPI DSI LCD control IO");
    esp_lcd_panel_io_handle_t mipi_dbi_io = NULL;
    // we use DBI interface to send LCD commands and parameters
    esp_lcd_dbi_io_config_t dbi_config = TD4101_PANEL_IO_DBI_CONFIG();
    ESP_ERROR_CHECK(esp_lcd_new_panel_io_dbi(mipi_dsi_bus, &dbi_config, &mipi_dbi_io));

    ESP_LOGI(TAG, "Install MIPI DSI LCD data panel");
    esp_lcd_panel_handle_t mipi_dpi_panel = NULL;
    esp_lcd_dpi_panel_config_t dpi_config = TD4101_540_960_PANEL_DPI_CONFIG(LCD_COLOR_FMT_RGB888); //LCD_COLOR_PIXEL_FORMAT_RGB565 LCD_COLOR_PIXEL_FORMAT_RGB888

    td4101_vendor_config_t vendor_config = {
        .mipi_config = {
            .dsi_bus = mipi_dsi_bus,
            .dpi_config = &dpi_config,
            .lane_num = 2,
        },
    };
    esp_lcd_panel_dev_config_t panel_config = {
        .reset_gpio_num = EXAMPLE_PIN_NUM_LCD_RST,
        .rgb_ele_order = LCD_RGB_ELEMENT_ORDER_RGB,
        .bits_per_pixel = 24,
        .vendor_config = &vendor_config,
    };
    ESP_LOGI(TAG, "esp_lcd_new_panel_td4101 panel");
    ESP_ERROR_CHECK(esp_lcd_new_panel_td4101(mipi_dbi_io, &panel_config, &mipi_dpi_panel));
    ESP_LOGI(TAG, "esp_lcd_panel_reset panel");
    ESP_ERROR_CHECK(esp_lcd_panel_reset(mipi_dpi_panel));
    ESP_LOGI(TAG, "esp_lcd_panel_init panel");
    ESP_ERROR_CHECK(esp_lcd_panel_init(mipi_dpi_panel));
    // turn on display
    ESP_ERROR_CHECK(esp_lcd_panel_disp_on_off(mipi_dpi_panel, true));
    // turn on backlight
    example_bsp_set_lcd_backlight(EXAMPLE_LCD_BK_LIGHT_ON_LEVEL);

    // DEBUG: Uncomment to test if MIPI DSI bus is working - shows color bars
    ESP_LOGI(TAG, "Setting test pattern - if you see color bars, MIPI DSI is working");
    esp_lcd_dpi_panel_set_pattern(mipi_dpi_panel, MIPI_DSI_PATTERN_BAR_VERTICAL);
    vTaskDelay(pdMS_TO_TICKS(3000));
    esp_lcd_dpi_panel_set_pattern(mipi_dpi_panel, MIPI_DSI_PATTERN_NONE); // Disable pattern for LVGL;

    ESP_LOGI(TAG, "Initialize LVGL library");
    lv_init();
    // create a lvgl display
    lv_display_t *display = lv_display_create(EXAMPLE_MIPI_DSI_LCD_H_RES, EXAMPLE_MIPI_DSI_LCD_V_RES);
    // associate the mipi panel handle to the display
    lv_display_set_user_data(display, mipi_dpi_panel);
    // set color depth
    lv_display_set_color_format(display, LV_COLOR_FORMAT_RGB888);
    // create draw buffer
    void *buf1 = NULL;
    void *buf2 = NULL;
    ESP_LOGI(TAG, "Allocate separate LVGL draw buffers");
    // Note:
    // Keep the display buffer in **internal** RAM can speed up the UI because LVGL uses it a lot and it should have a fast access time
    // This example allocate the buffer from PSRAM mainly because we want to save the internal RAM
    size_t draw_buffer_sz = EXAMPLE_MIPI_DSI_LCD_H_RES * EXAMPLE_LVGL_DRAW_BUF_LINES * sizeof(lv_color_t);
    buf1 = heap_caps_malloc(draw_buffer_sz, MALLOC_CAP_SPIRAM);
    assert(buf1);
    buf2 = heap_caps_malloc(draw_buffer_sz, MALLOC_CAP_SPIRAM);
    assert(buf2);
    // initialize LVGL draw buffers
    lv_display_set_buffers(display, buf1, buf2, draw_buffer_sz, LV_DISPLAY_RENDER_MODE_PARTIAL);
    // set the callback which can copy the rendered image to an area of the display
    lv_display_set_flush_cb(display, example_lvgl_flush_cb);

    ESP_LOGI(TAG, "Register DPI panel event callback for LVGL flush ready notification");
    esp_lcd_dpi_panel_event_callbacks_t cbs = {
        .on_color_trans_done = example_notify_lvgl_flush_ready,
    };
    ESP_ERROR_CHECK(esp_lcd_dpi_panel_register_event_callbacks(mipi_dpi_panel, &cbs, display));

    ESP_LOGI(TAG, "Use esp_timer as LVGL tick timer");
    const esp_timer_create_args_t lvgl_tick_timer_args = {
        .callback = &example_increase_lvgl_tick,
        .name = "lvgl_tick"
    };
    esp_timer_handle_t lvgl_tick_timer = NULL;
    ESP_ERROR_CHECK(esp_timer_create(&lvgl_tick_timer_args, &lvgl_tick_timer));
    ESP_ERROR_CHECK(esp_timer_start_periodic(lvgl_tick_timer, EXAMPLE_LVGL_TICK_PERIOD_MS * 1000));

    ESP_LOGI(TAG, "Create LVGL task");
    xTaskCreate(example_lvgl_port_task, "LVGL", EXAMPLE_LVGL_TASK_STACK_SIZE, NULL, EXAMPLE_LVGL_TASK_PRIORITY, NULL);

    ESP_LOGI(TAG, "Display LVGL Meter Widget");
    _lock_acquire(&lvgl_api_lock);
    example_lvgl_demo_ui(display);
    _lock_release(&lvgl_api_lock);
}

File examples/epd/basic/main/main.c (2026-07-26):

#include <stdio.h>
#include <string.h>
#include <unistd.h>
#include <fcntl.h>
#include <errno.h>
#include <sys/ioctl.h>
#include <sys/lock.h>
#include <sys/select.h>
#include "sdkconfig.h"
#include "freertos/FreeRTOS.h"
#include "freertos/task.h"
#include "freertos/semphr.h"
#include "esp_timer.h"
#include "esp_lcd_panel_ops.h"
#include "esp_lcd_mipi_dsi.h"
#include "esp_ldo_regulator.h"
#include "driver/gpio.h"
#include "driver/i2c_master.h"
#include "esp_err.h"
#include "esp_heap_caps.h"
#include "main.h"
#include "STC3115.h" 
#include "kxtj3_1057.h"
#include "rv3028.h"
#include "TPS65185.h"

#include "FastEPD.h"
#include "Roboto_Black_80.h"
#include "Roboto_Black_40.h"
#include "Courier_Prime_16.h"

static const char *TAG = "eInky-P4";

////////////////////////////////////////////
//////////// I2C EXPANDER //////////////////
////////////////////////////////////////////
#define I2C_MASTER_SCL_IO           29      /*!< GPIO number for I2C master clock */
#define I2C_MASTER_SDA_IO           28      /*!< GPIO number for I2C master data  */
#define I2C_MASTER_NUM              I2C_NUM_0 /*!< I2C master i2c port number */

#define KEEP_ON                     0

i2c_master_bus_handle_t i2c_bus_handle = NULL;
tca6408_handle_t tca_board = NULL;
tca6408_handle_t tca_display = NULL;
stc3115_handle_t stc3115_handle = NULL;
kxtj3_handle_t kxtj3_handle = NULL;
rv3028_handle_t rv3028_handle = NULL;
tps65185_handle_t epd_pmic_handle = NULL;

FASTEPDSTATE bbep;

static esp_err_t i2c_master_init(void) {
    // Configure the I2C bus
    i2c_master_bus_config_t bus_config = {
        .i2c_port = I2C_MASTER_NUM,           // Your existing I2C_NUM_0
        .sda_io_num = I2C_MASTER_SDA_IO,      // Your existing SDA pin
        .scl_io_num = I2C_MASTER_SCL_IO,      // Your existing SCL pin
        .clk_source = I2C_CLK_SRC_DEFAULT,    // Use default clock source
        .glitch_ignore_cnt = 100,             // Filter out glitches < 350ns
        .flags.enable_internal_pullup = true, // Equivalent to your pullup enables
    };

    // Initialize the bus and get handle
    esp_err_t err = i2c_new_master_bus(&bus_config, &i2c_bus_handle);
    if (err != ESP_OK) {
        ESP_LOGE(TAG, "Failed to initialize I2C bus: %s", esp_err_to_name(err));
        return err;
    }
    ESP_LOGI(TAG, "i2c_master_init ESP_OK");
    return ESP_OK;
}

/**
 * @brief Scan for I2C devices
 */
void i2c_scan_devices(void)
{
    uint8_t address, devices_found;
    devices_found = 0;
    printf("     0  1  2  3  4  5  6  7  8  9  a  b  c  d  e  f\r\n");
    for (int i = 0; i < 128; i += 16) {
        printf("%02x: ", i);
        for (int j = 0; j < 16; j++) {
            fflush(stdout);
            address = i + j;
            esp_err_t ret = i2c_master_probe(i2c_bus_handle, address, -1);
            if (ret == ESP_OK) {
                printf("%02x ", address);
                devices_found++;
            } else if (ret == ESP_ERR_TIMEOUT) {
                printf("UU ");
            } else {
                printf("-- ");
            }
        }
        printf("\r\n");
    }
}


/* -----------------------------------------------------------------------
 * Helper: draw a centred title bar at the top of the screen
 * ----------------------------------------------------------------------- */
static void draw_title(const char *text, int w, int h)
{
    (void)w;
    int bar_h = h / 12;
    bbepRectangle(&bbep, 0, 0, bbep.width - 1, bar_h, BBEP_BLACK, 1);
    bbepWriteString(&bbep, 8, bar_h / 4, (char *)text, FONT_16x16, BBEP_WHITE);
}

/* -----------------------------------------------------------------------
 * DEMO 1 – Font showcase  (full update)
 * Shows every available font at the same left margin so differences
 * in size are immediately obvious.
 * ----------------------------------------------------------------------- */
static void demo_fonts(void)
{
    int w = bbep.width;
    int h = bbep.height;
    int margin = w / 40;           /* ~20 px on 800-wide */
    int y;

    bbepFillScreen(&bbep, BBEP_WHITE);

    draw_title("DEMO 1 : FONT SHOWCASE", w, h);

    /* Roboto Black 80 */
    y = h / 4;
    bbepWriteStringCustom(&bbep, Roboto_Black_80, margin, y,
                          "Roboto 80", BBEP_BLACK);

    /* Roboto Black 40 */
    y += h / 5;
    bbepWriteStringCustom(&bbep, Roboto_Black_40, margin, y,
                          "Roboto Black 40pt", BBEP_BLACK);

    /* Courier Prime 16 */
    y += h / 8;
    bbepWriteStringCustom(&bbep, Courier_Prime_16, margin, y,
                          "Courier Prime 16 - fixed-width font", BBEP_BLACK);

    /* Built-in 12x16 */
    y += h / 16;
    bbepWriteString(&bbep, margin, y,
                    "Built-in FONT_12x16 - medium size", FONT_12x16, BBEP_BLACK);

    /* Built-in 8x8 */
    y += h / 18;
    bbepWriteString(&bbep, margin, y,
                    "Built-in FONT_8x8  - smallest built-in", FONT_8x8, BBEP_BLACK);

    /* Separator + note at bottom */
    y = h - h / 14;
    bbepDrawLine(&bbep, 0, y, w - 1, y, BBEP_BLACK);
    y += 4;
    bbepWriteString(&bbep, margin, y,
                    "FastEPD font demo", FONT_8x8, BBEP_BLACK);

    bbepFullUpdate(&bbep, CLEAR_SLOW, KEEP_ON, NULL);
    vTaskDelay(pdMS_TO_TICKS(5000));
}
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

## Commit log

2026-04-29 initial A260 mipi_demo
    [partitionTable.csv]
2026-05-07 added calendar demo and some fixes
    [STC3115.c, STC3115.h, TPS65185.c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]
2026-05-07 added schematic pdf
2026-07-26 added HW(schematic + PCB) for all tested EPD adapters
    [AllInOneAdapter-39pin.kicad_pcb, AllInOneAdapter-39pin.kicad_sch, AllInOneAdapter.kicad_pcb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]
